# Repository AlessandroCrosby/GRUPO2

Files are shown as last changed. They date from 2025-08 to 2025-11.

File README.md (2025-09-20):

# GRUPO 2
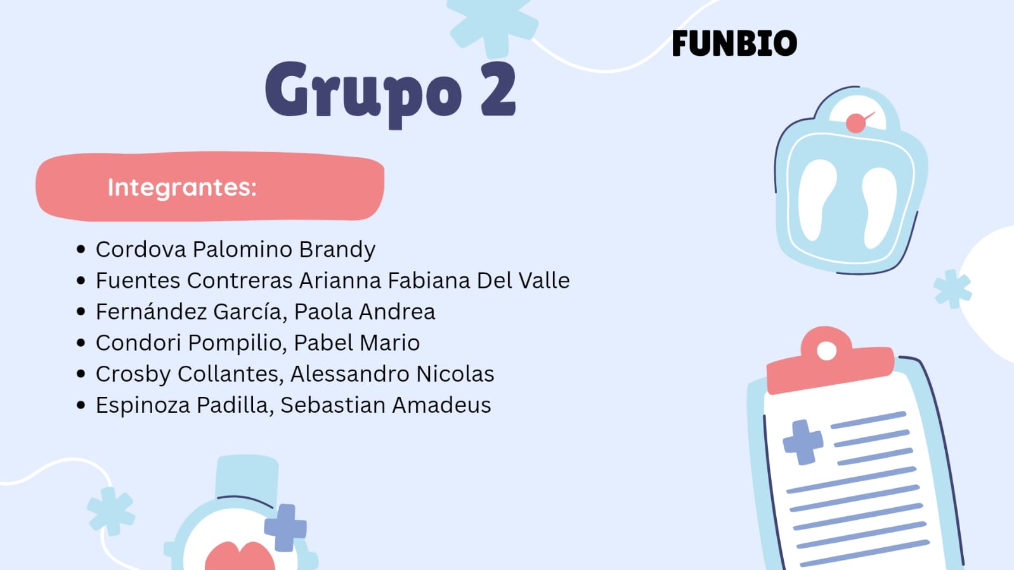
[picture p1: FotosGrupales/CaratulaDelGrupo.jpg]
CaratulaDelGrupo


## Descripción del Equipo - Fundamentos de Biodiseño
Este repositorio contiene el proyecto realizado por el Grupo 2 de estudiantes del 4.° ciclo de Ingeniería Biomédica para el curso de Fundamentos de Biodiseño. Nuestro objetivo fue resolver un desafío real mediante el diseño y desarrollo de un dispositivo biomédico, aplicando conocimiento en electrónica, modelado 3D, investigación y prototipado.

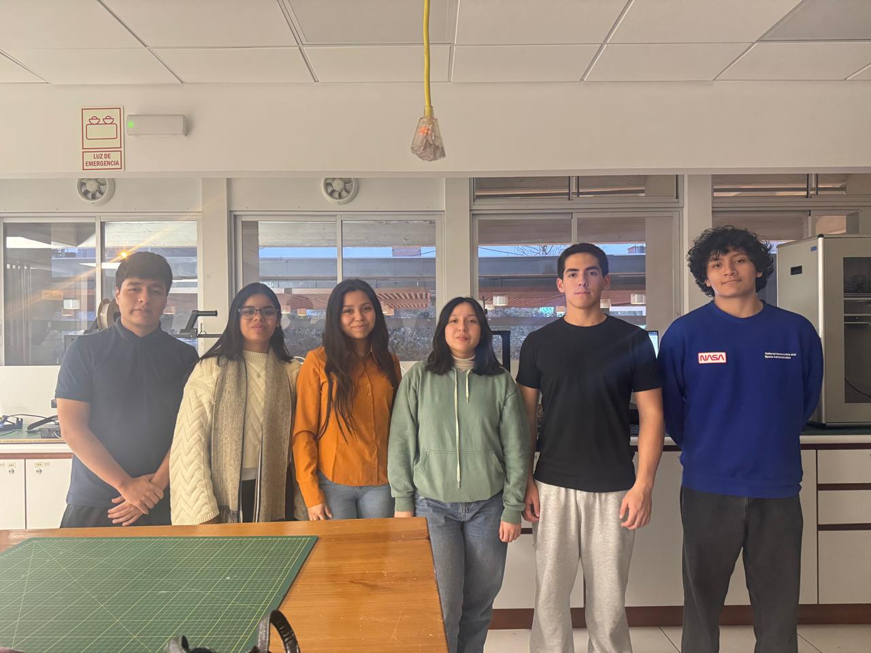
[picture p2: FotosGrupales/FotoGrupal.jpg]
FotoGrupal


## Integrantes del Equipo y Roles

### Condori Pompilio, Pabel Mario
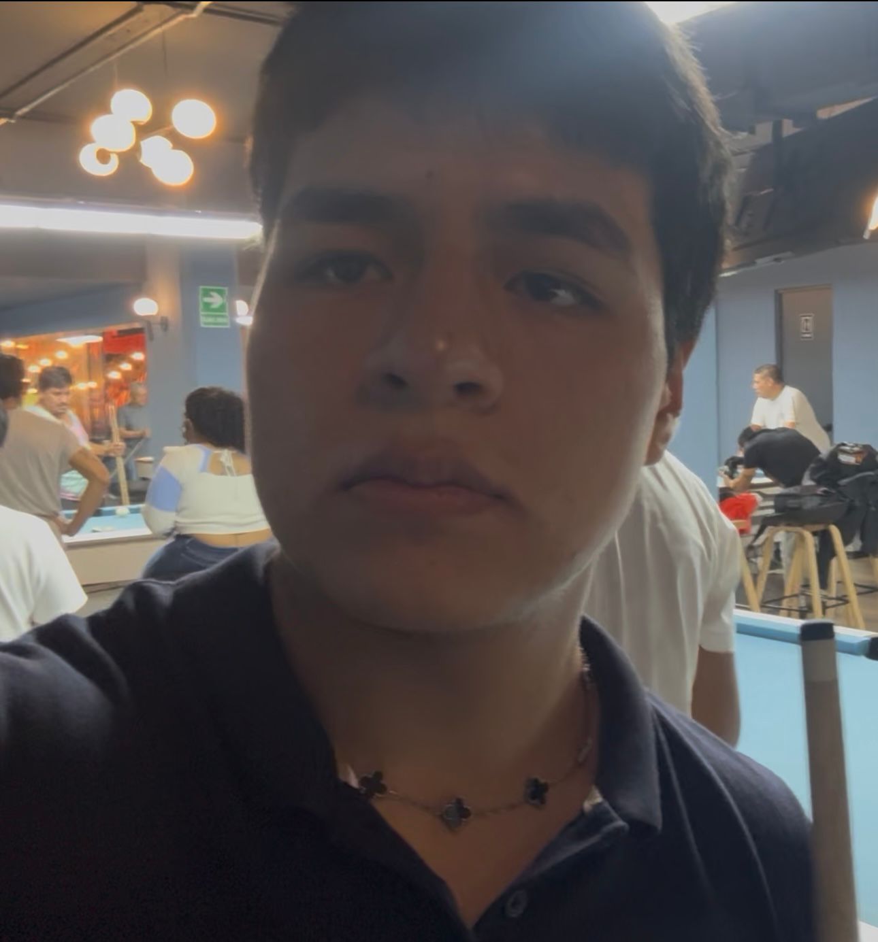
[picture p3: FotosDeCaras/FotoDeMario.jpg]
Mario


- Edad: 19 años
- Sobre mí: Hola soy Mario
- Rol: Modelado 3D
- Responsabilidades:
  - Creación de bocetos y prototipos
  - Selección de materiales

### Cordova Palomino, Brandy Abigail
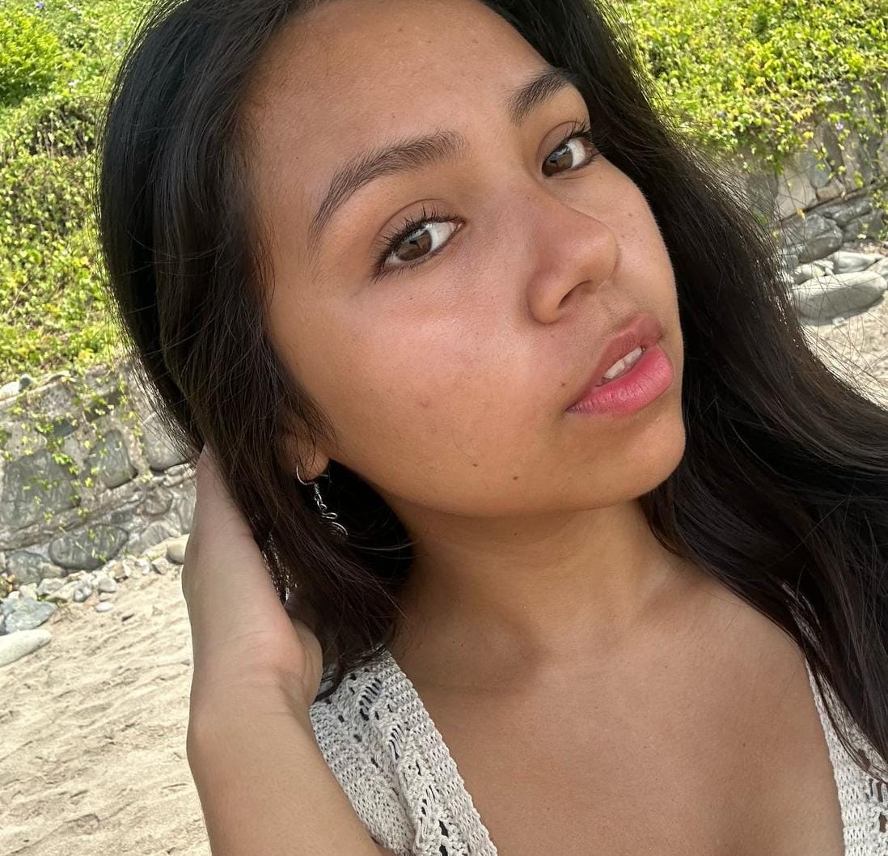
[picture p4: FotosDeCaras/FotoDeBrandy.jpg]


- Edad: 18 años
- Sobre mí: Me gusta cocinar y jugar
- Rol: Modelado 3D y prototipado
- Responsabilidades:
  - Diseño conceptual
  - Creación de bocetos
  - Modelado en 3D
  - Desarrollo en Cura

### Crosby Collantes, Alessandro Nicolas
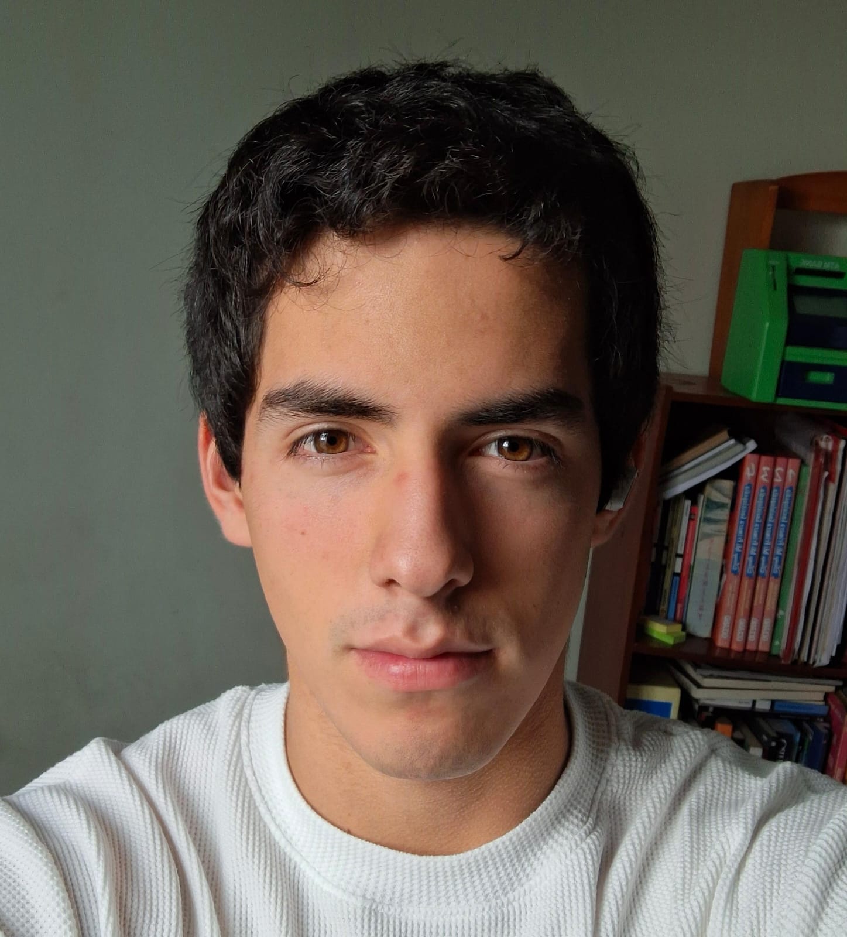
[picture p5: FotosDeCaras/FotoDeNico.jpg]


- Edad: 18 años
- Sobre mí: Me gusta ir al gimnasio y practico powerlifting :3.
- Rol: Gestión del repositorio y quien trae la laptop
- Responsabilidades:
  - Traer la laptop
    
### Espinoza Padilla, Sebastian Amadeus
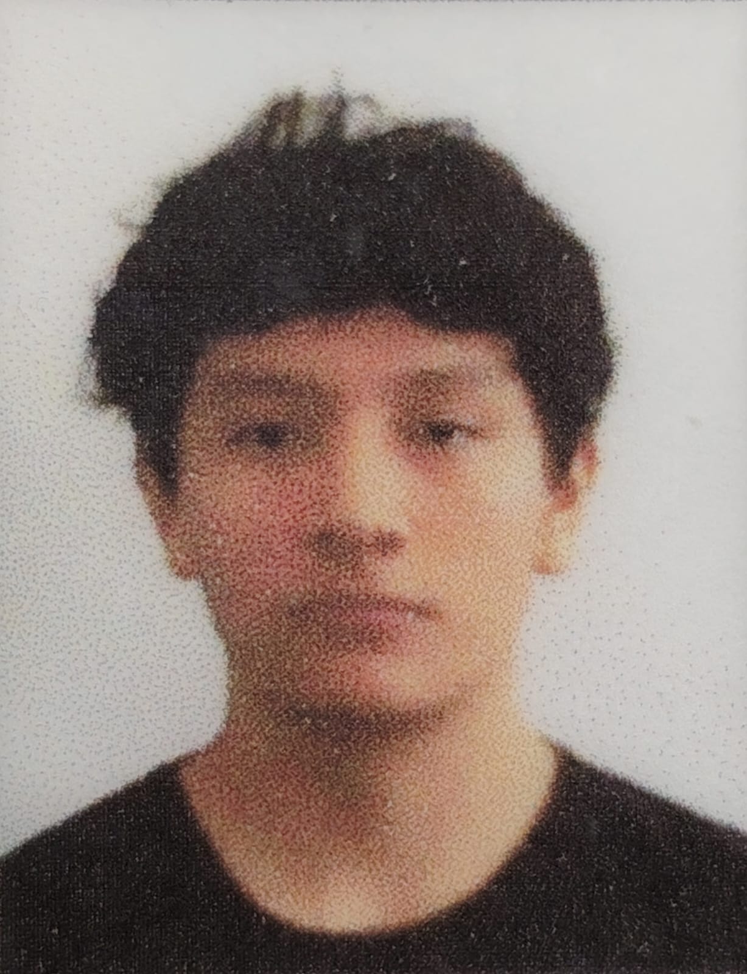
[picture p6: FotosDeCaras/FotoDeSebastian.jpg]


- Edad: 18
- Rol: Electrónica y programación , prototipo, investigador.
- Responsabilidades:
  - Investigación de avances tecnológicos
  - Apoyo en el sistema electrónico y por parte de la programación
  - Apoyo al realizar los bocetos
    
### Fernandez García, Paola Andrea
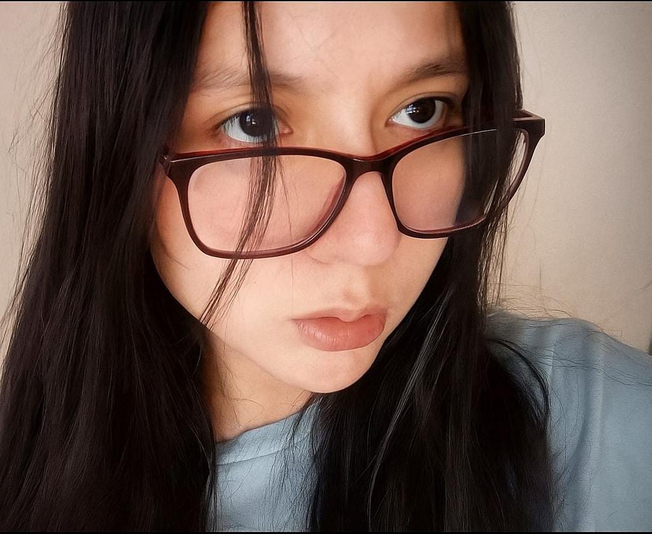
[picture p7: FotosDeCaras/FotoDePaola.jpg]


- Edad: 18
- Sobre mí: Me encanta hacer manualidades y origami. Apasionada por la tecnología.
- Rol: Electrónica
- Responsabilidades:
  - Apoyo en el desarrollo del sistema electrónico
    
### Fuentes Contreras, Arianna Fabiana del Valle
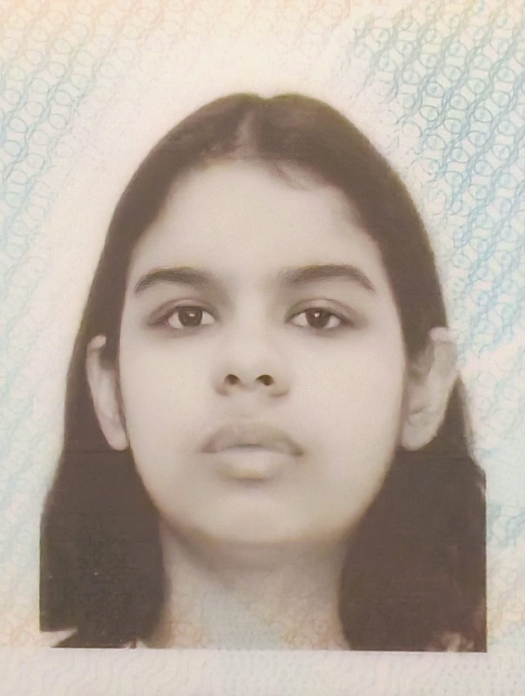
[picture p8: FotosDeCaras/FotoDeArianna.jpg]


- Edad: 18
- Sobre mi: Dibujar, tocar la guitarra, rugby y jugar con mi perro.
- Rol: Diseñadora de prototipo e investigador
- Responsabilidades:
  - Investigacion de tendencias y avances tecnológicos.
  - Realizar bocetos de los prototipos

### Gracias por visitar nuestro repositorio!

### Explora los archivos y conoce más sobre el desarrollo de nuestro dispositivo biomédico

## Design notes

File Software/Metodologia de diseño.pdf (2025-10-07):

# Metodologia de diseño

# CAJA NEGRA (sistema)

## Entradas

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
Captar y procesar
señales oculares | Controlar comandos

Transmitir comando
al controlador

Detectar obstáculos

Retroalimentar al
usuario

Corregir o detener
movimiento

Interpretar y ejecutar
comando

Controlar movimiento
de la silla

# Salidas

# Movimiento controlado de

la silla de ruedas.

## Retroalimentación visual o auditiva sobre el estado del

sistema.

## Mayor autonomía y seguridad

del usuario.

Los servomotores
mueven el brazo
robótico que acciona
el joystick de la silla
de ruedas.

El microcontrolador
convierte los
comandos en
señales para los
servomotores.

El microcontrolador
detiene o ajusta el
movimiento si
detecta peligro.

La app muestra
información sobre el
estado, velocidad,
batería y obstáculos.

Los comandos se
envían al
microcontrolador
(ESP32) mediante
Bluetooth o USB.

Sensores
ultrasónicos miden la
distancia y previenen
colisiones.

La app Eye Tracker
detecta y traduce los
movimientos oculares
en coordenadas para
controlar un cursor.

Los movimientos
oculares generan
comandos de
dirección y velocidad
en la app
“Wheelchair Control”

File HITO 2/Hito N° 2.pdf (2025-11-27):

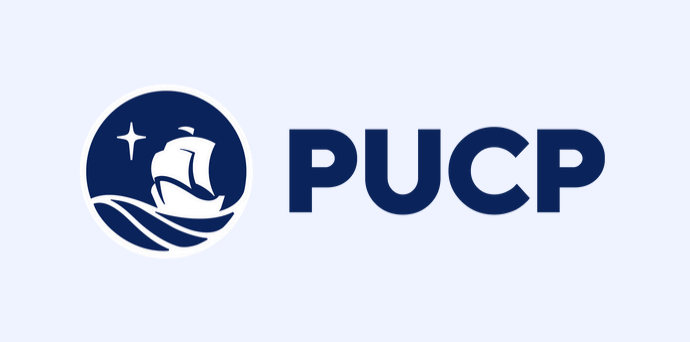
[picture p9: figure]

# EEyyee

# PPii

ll

oott Integrantes: AlessandroNicolasCrosbyCollantes Rol: Líder,creacióndeappmóvil“WheelchairEyeDriving” PabelMarioCondoriPompilio Rol: Hardware Arianna FabianaDelValleFuentesContreras Rol:EncargadadeldesarrollodelaApp PaolaAndrea FernándezGarcía Rol:Ensambladodelprototipo BrandyAbigailCordovaPalomino Rol:EncargadadelModelado3D SebastiánAmadeusEspinozaPadilla Rol: EncargadodelaElectrónica | GGrruuppoo 22

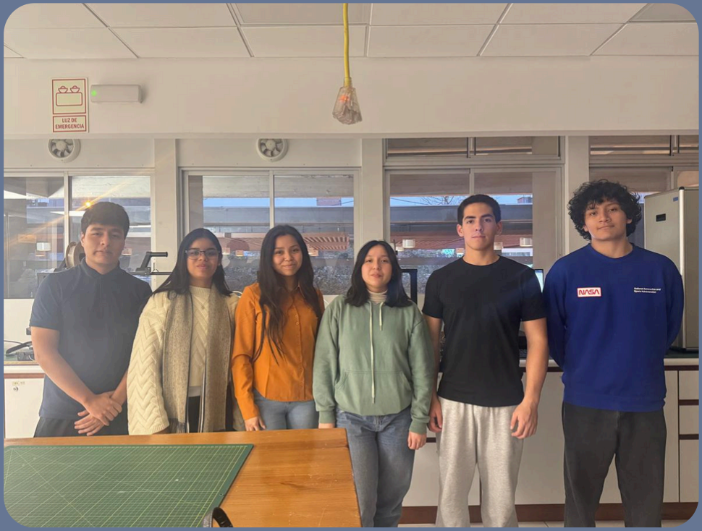
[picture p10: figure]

# PPrroobblleemmááttiiccaa

# Diagnóstico con EM

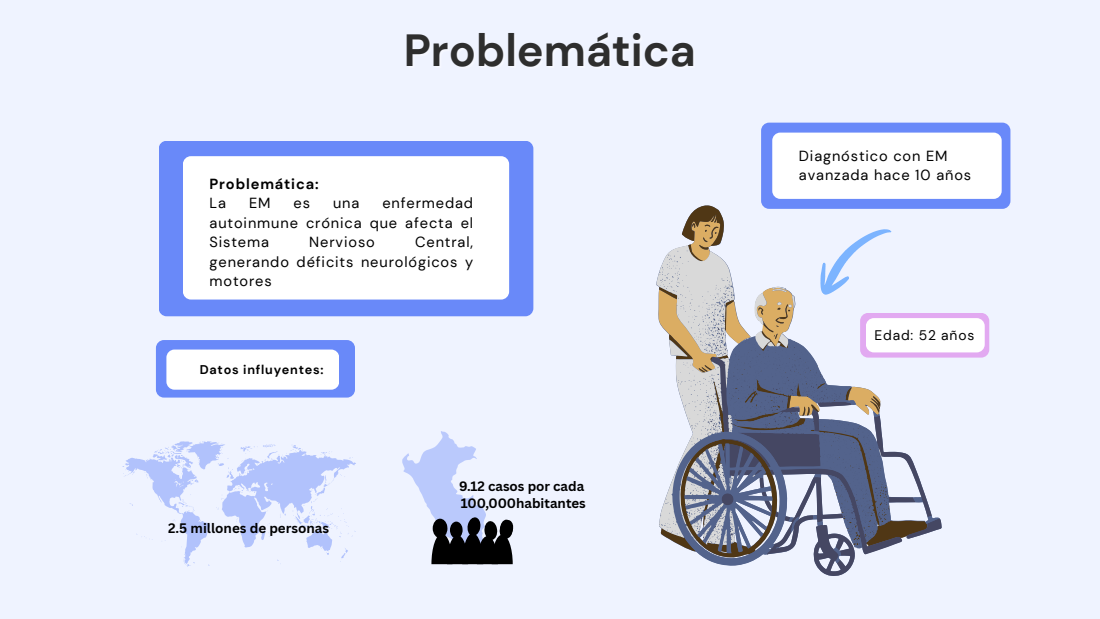
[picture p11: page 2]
Edad: 52; años; una; enfermedad; Sistema; Nervioso; Central,; Datos influyentes:

avanzada hace 10 años

Problemática:
autoinmune crónica que afecta el
generando déficits neurológicos y
motores

9.12 casos por cada
100,000habitantes

2.5 millones de personas

# Referencias Importantes del Estado del Arte

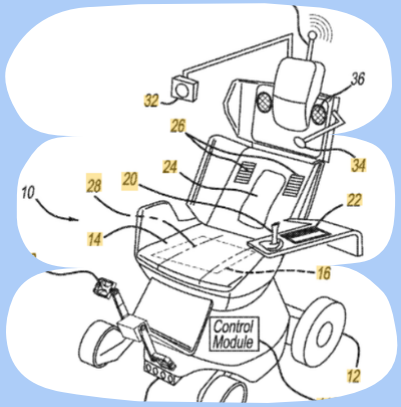
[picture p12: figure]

Sistema | de | control

# electrónico de una silla de ruedas eléctrica con GPS y mando local o remoto

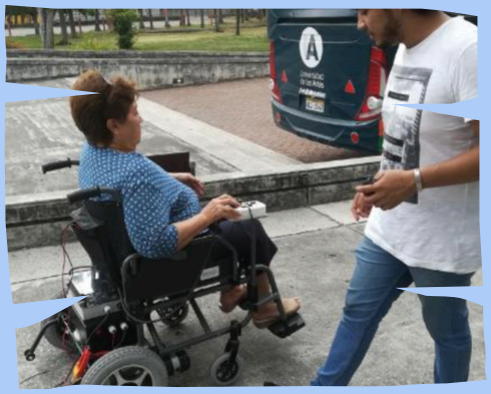
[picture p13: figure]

1 2

# Autonomous Wheelchair (Patente US20170266069A1)

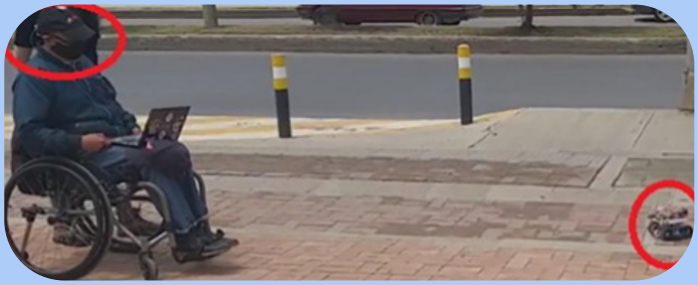
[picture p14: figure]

# 3 Prototipo de silla de ruedas

controlada por posición,
velocidad | y | orientación

# mediante el movimiento de la cabeza

M. M. Olivo Arroyo y E. G. Gallegos Díaz, Diseño e implementación de un sistema de control electrónico de una silla de ruedas eléctrica con ubicación GPS y mando local o remoto a través de una aplicación celular (Android), para personas con discapacidad motriz reducida en miembros inferiores, Universidad Politécnica Salesiana, Guayaquil, Ecuador, 2018. [En línea]. Disponible en: https://dspace.ups.edu.ec/bitstream/123456789/16059/1/UPS-GT002280.pdf
M. Lozano y M. Arceo, «US20170266069A1 - Autonomous wheelchair - Google Patents», 15 de marzo de 2016. Disponible en: https://patents.google.com/patent/US20170266069A1/en
A. X. González-Cely, M. Callejas-Cuervo, y T. Bastos-Filho, «Wheelchair prototype controlled by position, speed and orientation using head movement», HardwareX, vol. 11, p. e00306, abr. 2022, doi: 10.1016/j.ohx.2022.e00306

1 | 2 | TTrraannssmmiissiióónn | 3

# SSoolluucciióónn

# Funcionamiento en tres pasos:

Detección | Acción

# “Control electrónico de silla de ruedas por app con seguimiento facial.”

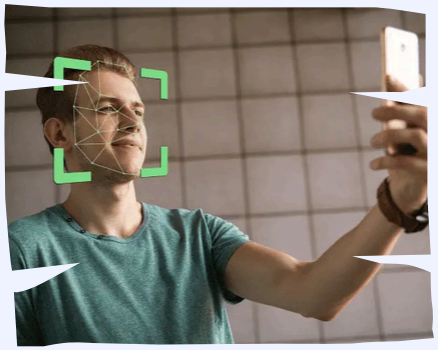
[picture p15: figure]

## La app detecta la cara (face-tracking) y la traduce en coordenadas o comandos

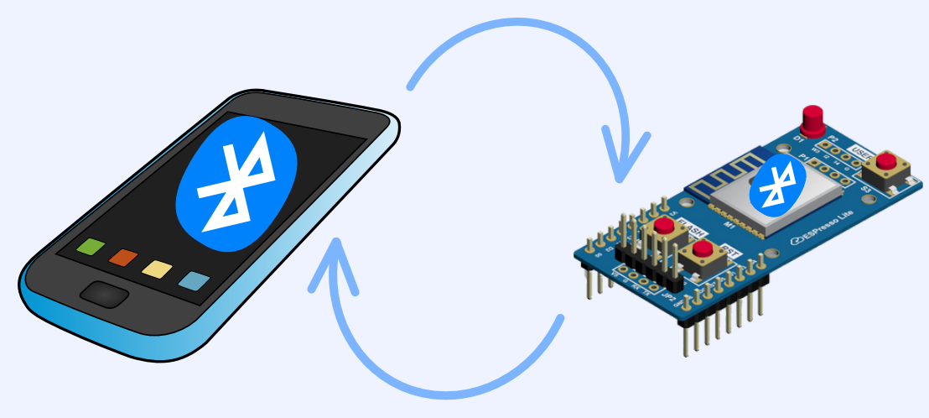
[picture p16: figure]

## El comando se transmite inalambricamente (Bluetooh) al microcontrolador (ESP32) ubicado en la “Brain box”

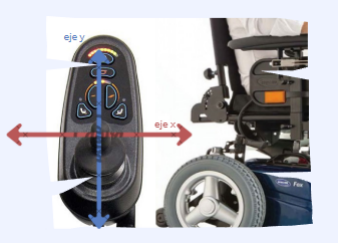
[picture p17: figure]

### El sistema acciona los servomotores de la “Mano Electrónica” que mueven físicamente el joystick de la silla

en el eje x y en el eje y.

Boceto inicial | Modelado 3D

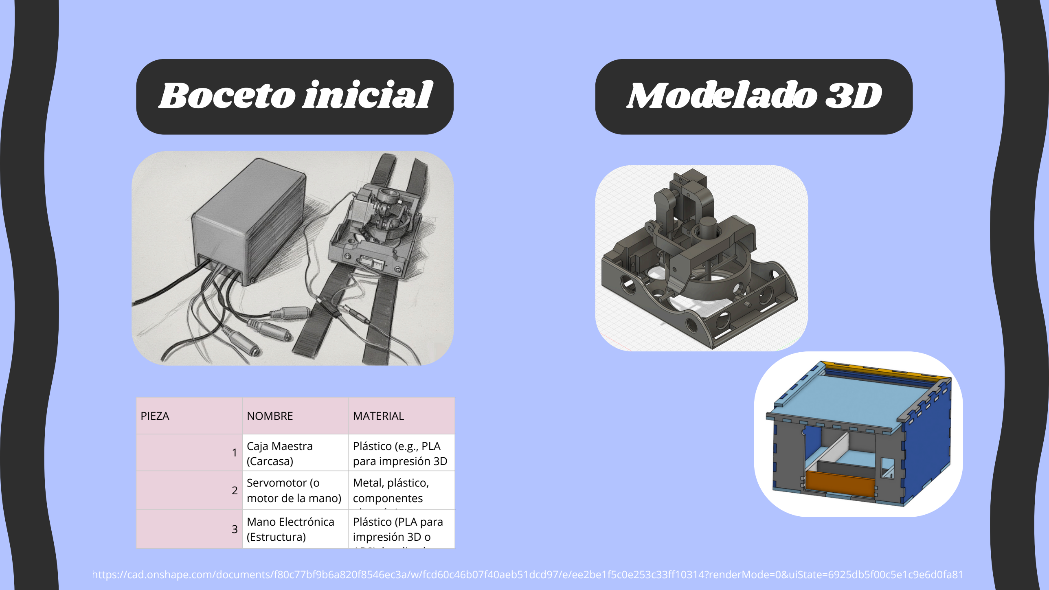
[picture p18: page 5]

PIEZA | NOMBRE | MATERIAL
1 | Caja Maestra (Carcasa) | Plástico (e.g., PLA para impresión 3D
2 | Servomotor (o motor de la mano) | Metal, plástico, componentes
3 | Mano Electrónica (Estructura) | Plástico (PLA para impresión 3D o

https://cad.onshape.com/documents/f80c77bf9b6a820f8546ec3a/w/fcd60c46b07f40aeb51dcd97/e/ee2be1f5c0e253c33ff10314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

# App:EyePilot

Esquema Interno de la App: | Vistas de la App

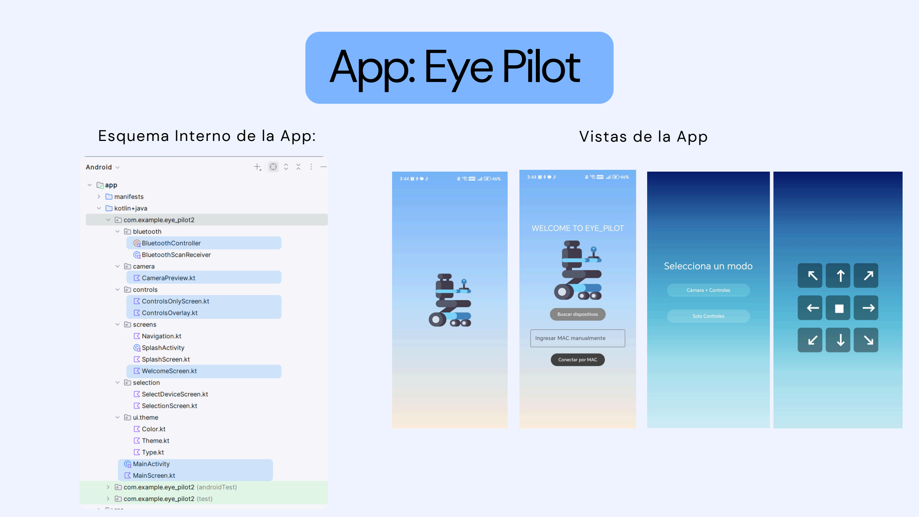
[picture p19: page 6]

# Esquemático del prototipo electrónico

# AAlliimmeennttaacciióónn

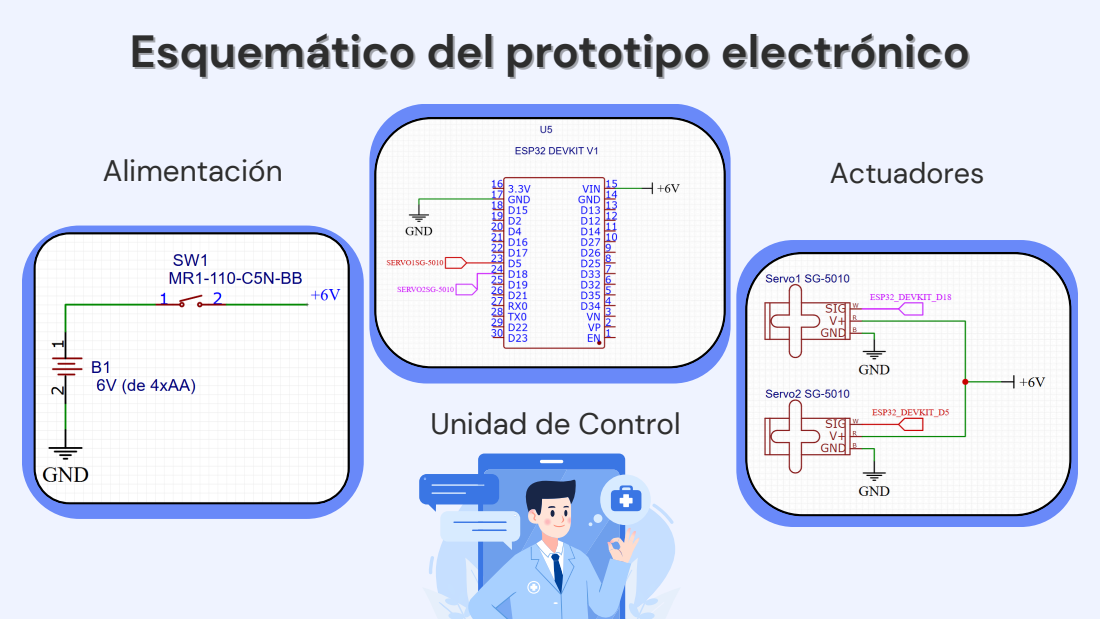
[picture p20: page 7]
AAccttuuaaddoorreess

Unidad de Control

# Componentes electrónicos

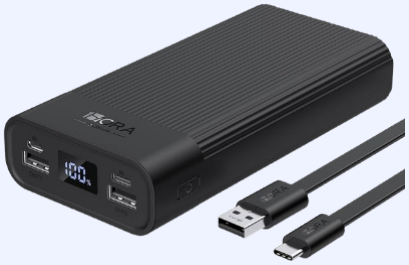
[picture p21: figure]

# Protoboard

# ESP32 DEVKIT V1

# Micro servomotor

# Batería portatil

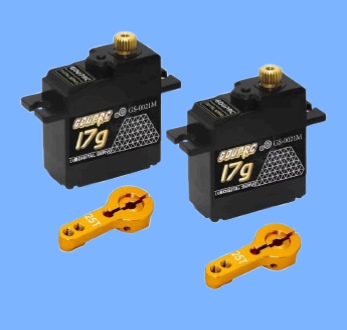
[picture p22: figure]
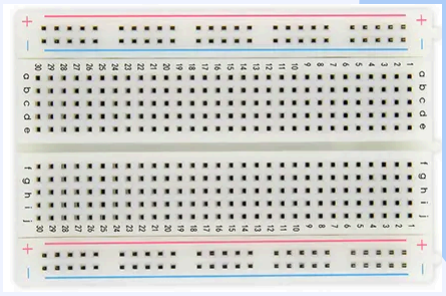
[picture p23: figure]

# Manufactura Digital: Impresión 3D

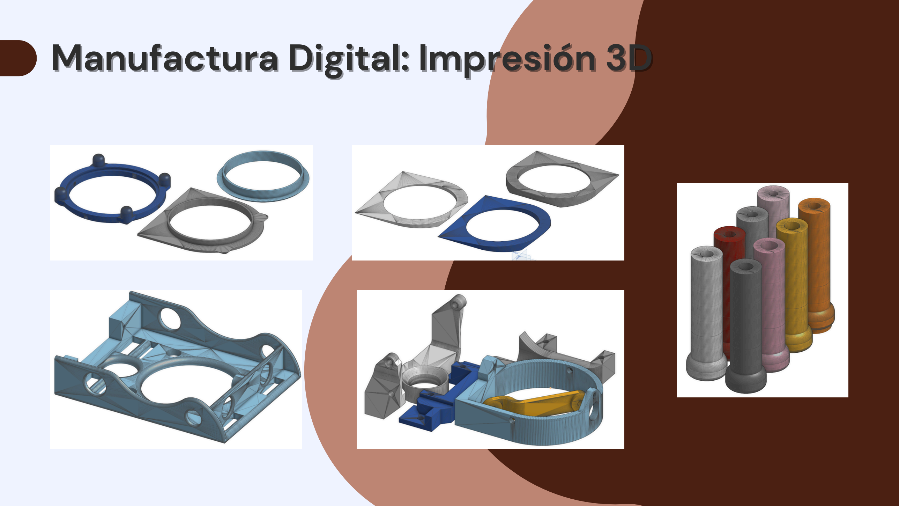
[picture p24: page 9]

# Manufactura Digital: Corte láser

# Switch

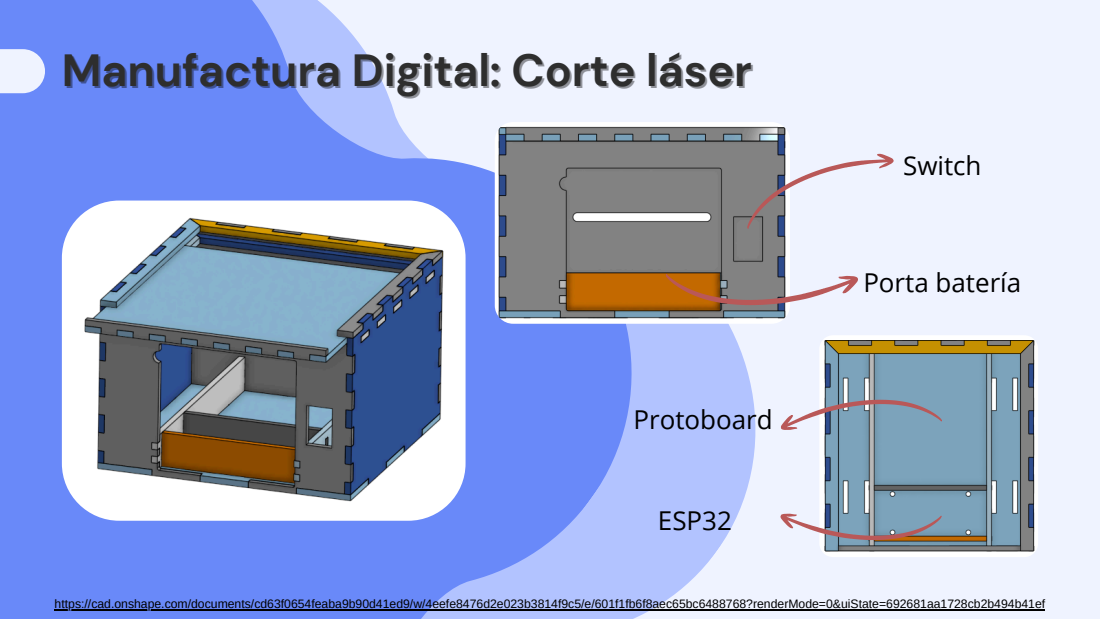
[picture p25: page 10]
Porta batería; Protoboard; ESP32

https://cad.onshape.com/documents/cd63f0654feaba9b90d41ed9/w/4eefe8476d2e023b3814f9c5/e/601f1fb6f8aec65bc6488768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

# Prototipo Integrado

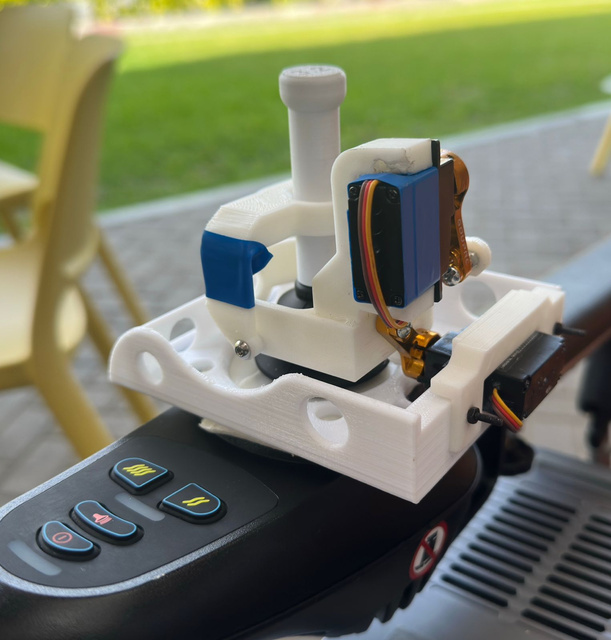
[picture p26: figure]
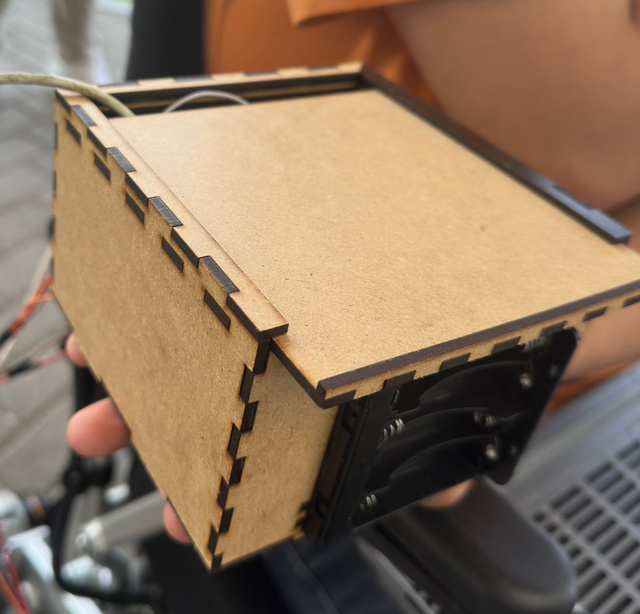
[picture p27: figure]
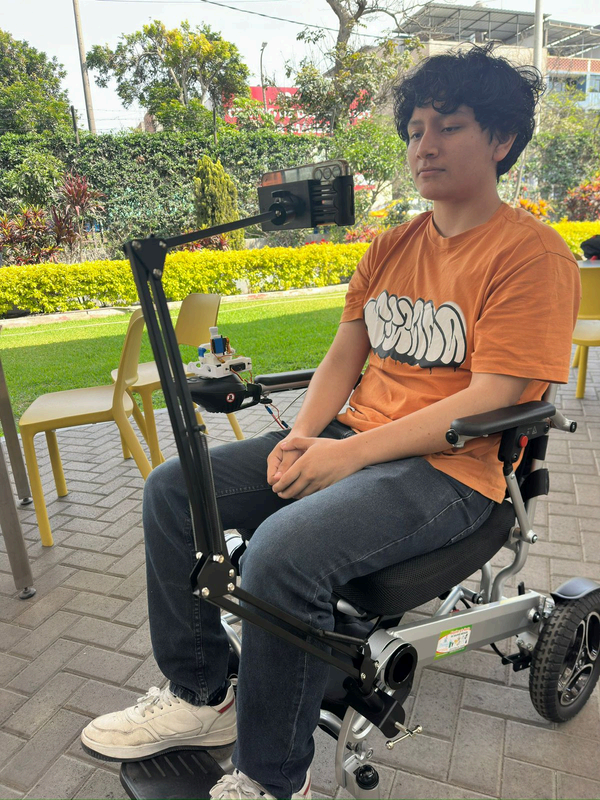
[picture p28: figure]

1 2

# Limitaciones

# Configuración de un Solo Dispositivo para Control y Cámara

# Ausencia de botón de emergencia integrado

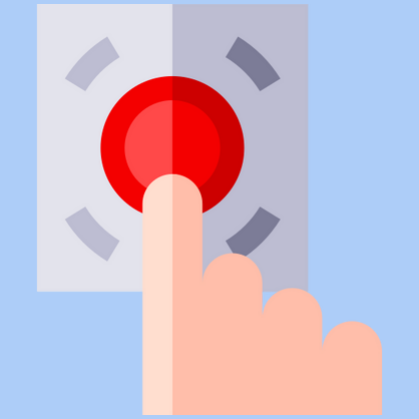
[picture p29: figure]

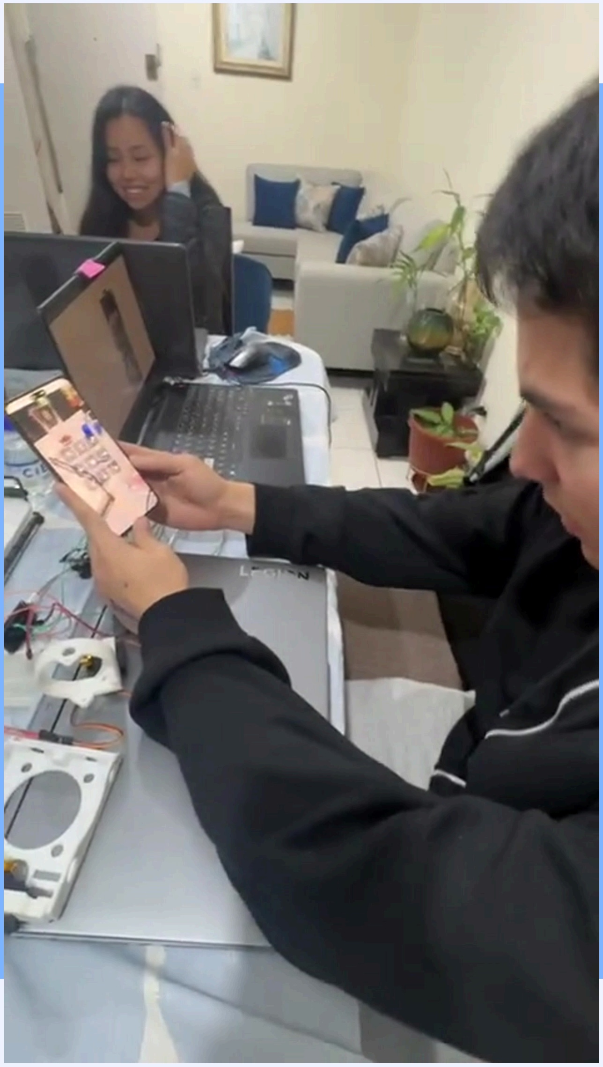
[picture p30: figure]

# Pruebas y Testeos

# Pruebas y Testeos

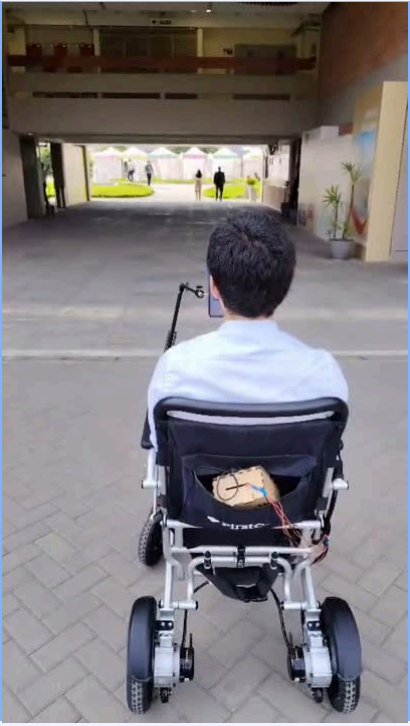
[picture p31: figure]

# Pruebas y Testeos

# Pruebas y Testeos

# MUCHAS

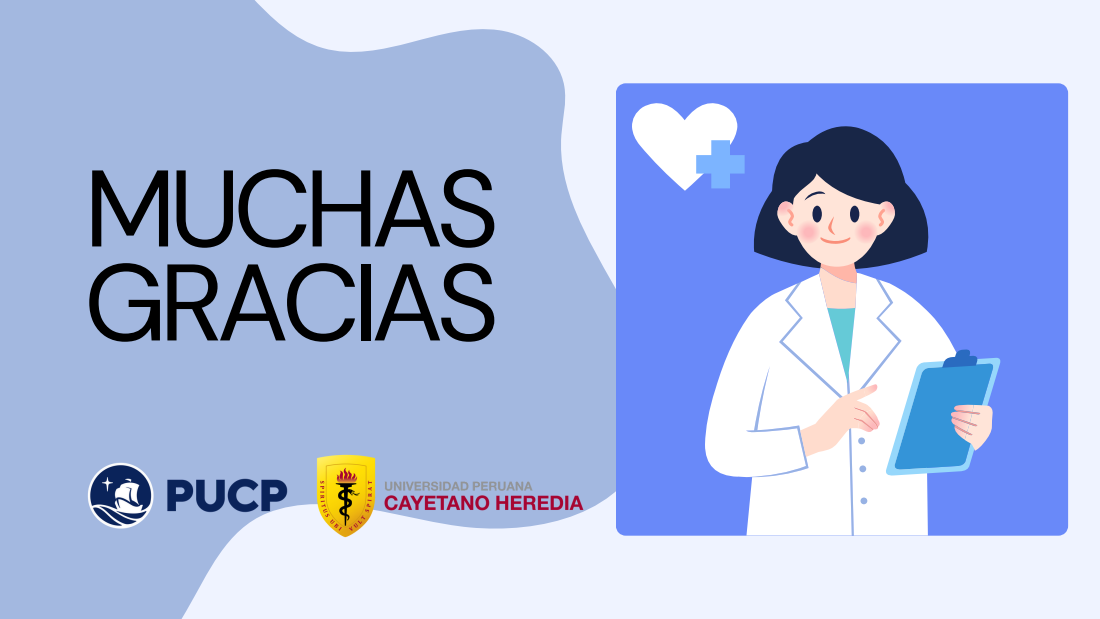
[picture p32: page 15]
GRACIAS

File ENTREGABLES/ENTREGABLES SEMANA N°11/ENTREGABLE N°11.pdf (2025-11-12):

Entregable N°11:

## Integración Hardware - Software - Manufactura digital

Autores:
Alessandro Nicolas Crosby Collantes Pabel Mario Condori Pompilio Arianna Fabiana Del Valle Fuentes Contreras Paola Andrea Fernández García Brandy Abigail Cordova Palomino Sebastián Amadeus Espinoza Padilla

Asesores:
Miguel Rogger Hoyos Alvitez Marco Mugaburu Celi
Shirley Pahuachon Nuñez

Curso:
Fundamentos de Biodiseño – Ciclo IV

Universidad Peruana Cayetano Heredia Facultad de Ciencias e Ingeniería Noviembre 2025

## Verificación de Diseño - SOFTWARE

Tabla de Verificación de Diseño (Software)

Requisito Funcional / No Funcional | Descripción del Componente o Función a Verificar | Método de Verificación (Prueba / Revisión / Simulación) | Criterio de Aceptación | Resultado (Cumple / No cumple) | Observaciones / Recomendacio nes
RF1 – Captar y procesar señales oculares | El sistema debe reconocer la dirección de la mirada y traducirla en comandos. | Prueba funcional en entorno controlado con cámara Android. | Reconocimien to ≥90% en entorno iluminado. | Cumple parcialmente | Precisión baja en baja luz; se recomienda calibración adaptativa.
RF2 – Controlar comandos de movimiento | La app debe interpretar el movimiento ocular para enviar comandos | Simulación con 4 direcciones (arriba, abajo, izq, der) | Tasa de error <10%. | Cumple | Fluidez adecuada, sin retrasos perceptibles.
RF3 – Transmisión Bluetooth | Comunicación entre app Android y módulo ESP32 | Prueba de conexión continua por 60 min. | Pérdida de conexión <1% | Cumple | Comunicación estable durante test prolongado.
RF4 – Interpretación de comandos (ESP32) | Software debe enviar datos correctos a microcontrola dor. | Revisión de código y trazado serial. | Señal reconocida en >95% de casos | Cumple | Comunicación estable, latencia promedio <100 ms.
RF5 – Interfaz de usuario | Interfaz visual clara y accesible | Prueba de usabilidad con usuario simulado | Usuario identifica comandos sin asistencia. | Cumple | Diseño intuitivo, buen contraste visual.
RF6 – Seguridad en fallos | Parada automática en error de conexión. | Simulación de desconexión intencional | Detención inmediata del sistema. | Cumple | Sistema detiene movimiento al perder conexión.

RNF1 – Usabilidad | Curva de aprendizaje ≤15 min. | Evaluación con usuario simulado | 100% comprende funciones básicas en <15 min. | Cumple | Interfaz intuitiva, requiere capacitación mínima.
RNF2 – Rendimiento | Procesamient o fluido sin retrasos notables. | Cronometría de respuesta visual–acción. | Latencia ≤0.2 s. | Cumple | Respuesta inmediata a estímulos visuales.
RNF3 – Fiabilidad | Prueba de operación continua 60 min. | Prueba de estrés. | Sin reinicios ni cuelgues. | Cumple parcialmente | Leve ralentización tras 45 min; optimizar gestión de memoria
RNF4 – Seguridad del sistema | Evita activaciones involuntarias | Pruebas de error ocular y parpadeo. | Activaciones <5%. | Cumple | Confirmación por doble fijación evita falsos positivos.

Tabla de Verificación del Prototipo con Funcionalidades Mixtas (Software / Hardware)

Subsiste ma | Elemento Verificad o | Tipo de Compone nte | Criterio de Verificació n | Resulta do Espera do | Resultad o Obtenido | Cumple / No cumple | Observac iones
Eye-Trac king – App | Procesam iento y transmisi ón de señales | Software + Sensor | Datos reconocidos y enviados correctame nte vía Bluetooth | Señales transmit idas sin pérdida | Transmisi ón estable | Cumple | Comunica ción óptima entre módulos.
App Android – ESP32 | Comunica ción bidireccio nal | Software + Hardware | Sincronizac ión entre interfaz y microcontr olador | Sin retrasos >0.2 s | Latencia 0.1 s | Cumple | Sistema fluido y estable.
ESP32 – Servomot ores | Ejecución de comandos | Software embebido | Comando recibido = movimiento correcto | Movimi ento preciso del joystick | Movimie nto suave y exacto | Cumple | Se mantiene control direccion al correcto.

Botón de emergenci a | Parada inmediata | Hardware + Software | Detención automática ante error | Sistema detiene acción | Cumple | Cumple | Función de seguridad validada.
Sensores ultrasónic os | Detección de obstáculo s | Hardware + Software | Emisión de alerta y corrección de trayectoria | Correcci ón automát ica al detectar objeto | Parcial | No cumple totalment e | Falta respuesta en ángulo ciego lateral.

Evaluación de Requerimientos No Cumplidos o a Replantear

Requisito | Situación Actual | Motivo del Incumplimiento / Riesgo | Acción Correctiva o Replanteamiento
RF1 – Precisión del eye-tracking | Cumple parcialmente | Variabilidad por condiciones de iluminación | Implementar calibración dinámica o sensor infrarrojo.
RNF3 – Fiabilidad (uso prolongado) | Cumple parcialmente | Gestión ineficiente de memoria en app | Optimizar código y liberar buffers tras cada sesión.
Sensor ultrasónico lateral | No cumple completamente | Ángulo muerto no cubierto por el sensor | Añadir sensor adicional o algoritmo de fusión de datos.

## Verificación de Diseño - Hardware

Tabla de Verificación de Diseño (Hardware)

Componente / Subsistema | Método de verificación | Criterio de aceptación | Resultado | Observaciones / Recomendaciones
Carcasa + ESP32 + batería + drivers + cableado | Medición con balanza | ≤ 0.80 kg | Cumple | Aunque con las bases que se tenía cumple, se realizarán pruebas con todo completo
Batería + consumo total | Prueba en uso continuo (movimientos/ BT) | ≥ 4 h | No cumple totalmente | Realizar unas pruebas más para tener bien en claro

E-STOP + lógica de corte | Prueba física: pulsación durante movimiento | Detención inmediata | Cumple | Se detiene si la persona no esta mirando ademas de desactivar el mecanismo en cualquier momento con el switch
Power / Reset accesibles | Inspección + prueba | Accesibles sin herramientas | Cumple | Reubicar si hay interferencias con el apoyabrazos, aun se realizara prueba.
Carcasa y anclajes | Inspección + plantilla | No invade ruedas/apoyab razos; no juego >2 mm | Cumple | En teoría cumple pero se realizará prueba.
Carcasa + soportes | Prueba de vibración/golp e leve | Sin fisuras; tornillos sin aflojar | Cumple | En teoría cumple pero se realizará prueba.
Servomotores + acople a joystick | Prueba funcional con cargas | Par ≥ requerido; seguimiento suave | Cumple | En teoría cumple pero se realizará prueba.
LEDs/buzzer | Prueba de patrones | Estados distinguibles (conectado, error, stop) | Cumple | En la aplicación podrá observarse el estado
Drivers/servos /carcasa | Medición con termómetro IR | Carcasa <45 °C; driver <70 °C | Cumple | No se usará ventilación pero las siguiente pruebas de uso lo determinaran mejor

Vídeo del funcionamiento piloto de EyePilot: https://youtube.com/shorts/qDQIfGdBrkY?feature=share


Foto del prototipo:

Código del Arduino IDE:



Códigos del Android App Studio:

- Código 1:


- Código 2:

package com.example.eyepilot_app

import android.Manifest

import android.bluetooth.BluetoothAdapter

import android.bluetooth.BluetoothDevice

import android.bluetooth.BluetoothManager

import android.content.pm.PackageManager

import android.os.Build

import android.os.Bundle

import android.util.Log

import androidx.activity.ComponentActivity

import androidx.activity.compose.setContent

import androidx.activity.compose.rememberLauncherForActivityResult

import androidx.activity.result.contract.ActivityResultContracts

import androidx.camera.core.CameraSelector

import androidx.camera.core.Preview

import androidx.camera.lifecycle.ProcessCameraProvider

import androidx.camera.view.PreviewView

import androidx.compose.foundation.layout.*

import androidx.compose.material3.Scaffold

import androidx.compose.runtime.*

import androidx.compose.ui.Alignment

import androidx.compose.ui.Modifier

import androidx.compose.ui.viewinterop.AndroidView import androidx.core.content.ContextCompat

import androidx.lifecycle.compose.LocalLifecycleOwner

class MainActivity : ComponentActivity() {

private var bluetoothAdapter: BluetoothAdapter? = null

private val espMac = "00:22:04:AB:CD:EF"

override fun onCreate(savedInstanceState: Bundle?) {

super.onCreate(savedInstanceState)

setContent {

CameraPreview(modifier = Modifier.fillMaxSize())

}

val bluetoothManager = getSystemService(BLUETOOTH_SERVICE) as BluetoothManager

bluetoothAdapter = bluetoothManager.adapter

requestBluetoothPermissions()

connectToESP()

setContent {

Scaffold(modifier = Modifier.fillMaxSize()) { padding ->

val lifecycleOwner = LocalLifecycleOwner.current

var hasCameraPermission by remember { mutableStateOf(false) }

val cameraPermissionLauncher = rememberLauncherForActivityResult(

contract = ActivityResultContracts.RequestPermission(),

onResult = { granted: Boolean -> hasCameraPermission = granted }

)

LaunchedEffect(Unit) {

cameraPermissionLauncher.launch(Manifest.permission.CAMERA)

}

Box(

modifier = Modifier

.fillMaxSize()

.padding(padding)

) {

if (hasCameraPermission) {

CameraPreview(

modifier = Modifier.fillMaxSize(),

lifecycleOwner = lifecycleOwner

)

}

ControlsOverlay(

modifier = Modifier.align(Alignment.Center),

sendCommand = { cmd -> BluetoothController.sendCommand(cmd) }

)

}

}

}

}

private fun requestBluetoothPermissions() {

if (Build.VERSION.SDK_INT >= Build.VERSION_CODES.S) {

val permissions = arrayOf(

Manifest.permission.BLUETOOTH_CONNECT,

Manifest.permission.BLUETOOTH_SCAN

)

val missing = permissions.any {

checkSelfPermission(it) != PackageManager.PERMISSION_GRANTED

}

if (missing) {

requestPermissions(permissions, 1001)

}

}

}

private fun connectToESP() {

try {

val device: BluetoothDevice? = bluetoothAdapter?.getRemoteDevice(espMac)

if (device != null) {

BluetoothController.connect(device)

} else {

Log.e("BT", "Device not found")

}

} catch (e: SecurityException) {

Log.e("BT", "Permission denied", e)

}

}

}

@Composable

fun CameraPreview(

modifier: Modifier,

lifecycleOwner: androidx.lifecycle.LifecycleOwner

) {

AndroidView(

modifier = modifier,

factory = { ctx ->

val previewView = PreviewView(ctx)

val cameraProviderFuture = ProcessCameraProvider.getInstance(ctx)

cameraProviderFuture.addListener({

val cameraProvider = cameraProviderFuture.get()

val preview = Preview.Builder().build().also {

it.setSurfaceProvider(previewView.surfaceProvider)

}

try {

cameraProvider.unbindAll()

cameraProvider.bindToLifecycle(

lifecycleOwner,

CameraSelector.DEFAULT_BACK_CAMERA,

preview

)

} catch (e: Exception) {

e.printStackTrace()

}

}, ContextCompat.getMainExecutor(ctx))

previewView

}

)

}

- Código 3:

package com.example.eyepilot_app

import androidx.compose.foundation.layout.*

import androidx.compose.foundation.shape.RoundedCornerShape

import androidx.compose.material3.Button

import androidx.compose.material3.ButtonDefaults

import androidx.compose.material3.Text

import androidx.compose.runtime.Composable

import androidx.compose.ui.Alignment

import androidx.compose.ui.Modifier

import androidx.compose.ui.graphics.Color

import androidx.compose.ui.unit.dp

import androidx.compose.ui.unit.sp

import androidx.compose.ui.text.font.FontWeight

import androidx.compose.ui.res.painterResource

import androidx.compose.foundation.Image

@Composable

fun ControlsOverlay(modifier: Modifier = Modifier, sendCommand: (String) -> Unit) {

val buttonModifier = Modifier.size(80.dp).padding(5.dp)

val color = ButtonDefaults.buttonColors(containerColor = Color.Black.copy(alpha = 0.4f))

Column(

modifier = modifier,

horizontalAlignment = Alignment.CenterHorizontally,

verticalArrangement = Arrangement.Center

) {

Row {

Button(onClick = { sendCommand("UP_LEFT") },

modifier = buttonModifier, colors = color, shape = RoundedCornerShape(9.dp)) { Text("↖", fontSize = 38.sp, fontWeight = FontWeight.Bold) }

Button(onClick = { sendCommand("UP") },

modifier = buttonModifier, colors = color, shape = RoundedCornerShape(9.dp)) { Text("↑", fontSize = 38.sp, fontWeight = FontWeight.Bold) }

Button(onClick = { sendCommand("UP_RIGHT") },

modifier = buttonModifier, colors = color, shape = RoundedCornerShape(9.dp)) { Text("↗", fontSize = 38.sp, fontWeight = FontWeight.Bold) }

}

Spacer(Modifier.height(12.dp))

Row {

Button(onClick = { sendCommand("LEFT") }, modifier = buttonModifier, colors = color, shape = RoundedCornerShape(9.dp)) { Text("←", fontSize = 38.sp, fontWeight = FontWeight.Bold) }

Button(onClick = { sendCommand("STOP") },

modifier = buttonModifier, colors = color, shape = RoundedCornerShape(9.dp)) { Text("■", fontSize = 38.sp, fontWeight = FontWeight.Bold) }

Button(onClick = { sendCommand("RIGHT") },

modifier = buttonModifier, colors = color, shape = RoundedCornerShape(9.dp)) { Text("→", fontSize = 38.sp, fontWeight = FontWeight.Bold) }

}

Spacer(Modifier.height(12.dp))

Row {

Button(onClick = { sendCommand("DOWN_LEFT") },

modifier = buttonModifier, colors = color, shape = RoundedCornerShape(9.dp)) { Text("↙", fontSize = 38.sp, fontWeight = FontWeight.Bold) }

Button(onClick = { sendCommand("DOWN") },

modifier = buttonModifier, colors = color, shape = RoundedCornerShape(9.dp)) { Text("↓", fontSize = 38.sp, fontWeight = FontWeight.Bold) }

Button(onClick = { sendCommand("DOWN_RIGHT") },

modifier = buttonModifier, colors = color, shape = RoundedCornerShape(9.dp)) { Text("↘", fontSize = 38.sp, fontWeight = FontWeight.Bold) }

}

}

}

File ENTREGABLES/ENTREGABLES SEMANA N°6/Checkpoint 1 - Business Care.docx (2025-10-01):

Checkpoint 1 – Business Case

1. Situación inicial
El paciente con esclerosis múltiple avanzada presenta disartria severa y habla ininteligible, lo que limita su autonomía comunicativa, participación social y calidad de vida. Los sistemas de comunicación actuales que ha probado son lentos, poco accesibles y requieren esfuerzos físicos/cognitivos que aumentan su fatiga.

2. Objetivos estratégicos

- Técnicos: Desarrollar un sistema aumentativo y alternativo de comunicación (SAAC) multimodal (control ocular, gestual o BCI) que sea accesible, personalizable y de bajo esfuerzo.
- Económicos: Prototipo de bajo costo en comparación con soluciones comerciales (>10,000 USD).
- Organizativos: Integrar al equipo interdisciplinario (ingenieros biomédicos, terapeutas de lenguaje, médicos rehabilitadores) en un proceso de co-diseño con la familia del paciente.

3. Valor añadido

- Usuario: Autonomía comunicativa y emocional, reducción del aislamiento social.
- Empresa/Universidad: Desarrollo de prototipo biomédico con potencial de escalamiento y aplicación en otros pacientes con disartria severa.
- Sociedad: Mejora de inclusión y accesibilidad tecnológica para personas con discapacidades motoras y del habla.

4. Stakeholders

- Usuario final: Paciente con EM avanzada y disartria severa.
- Cuidadores primarios: Esposa e hijo adolescente.
- Equipo clínico: Neurólogo, fisiatra, terapeuta de lenguaje, fisioterapeuta, psicólogo.
- Otros: Institución académica, posibles fabricantes de dispositivos médicos, aseguradoras de salud.

5. Competencias y equipo

- Conocimiento de bioinstrumentación, electrónica, interfaces HMI, software accesible y procesamiento de señales biomédicas.
- Apoyo clínico en logopedia y rehabilitación para validar el sistema.
- Recursos disponibles: laboratorio universitario, open-hardware (OpenBCI), licencias de software de desarrollo.

6. Planificación inicial

- Cronograma preliminar:
  - Semana 1–2-3-4: investigación de usuario y benchmarking de tecnologías.
  - Semana 5-6-7-8: diseño conceptual, selección de sensores y hardware.
  - Semana 9-10-11-12: prototipado inicial y pruebas en laboratorio.
  - Semana 13-14-15-16: pruebas piloto con paciente, iteración de mejoras.
- Presupuesto inicial: S/.200–300 (hardware, sensores, software, manufactura).
- Riesgos:
  - Fatiga ocular o deterioro visual limita el uso de eye-tracking.
  - Problemas de usabilidad (interfaz demasiado compleja).
  - Falta de financiamiento sostenido.
  - Aceptación del usuario/familia si el sistema no se adapta a sus rutinas.

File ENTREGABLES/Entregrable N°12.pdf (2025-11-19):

### Entregable N°12:

### Pruebas de uso del prototipo de baja fidelidad según plan de usabilidad

### Autores:

### Alessandro Nicolas Crosby Collantes Pabel Mario Condori Pompilio Arianna Fabiana Del Valle Fuentes Contreras Paola Andrea Fernández García Brandy Abigail Cordova Palomino Sebastián Amadeus Espinoza Padilla

### Asesores:

### Miguel Rogger Hoyos Alvitez Marco Mugaburu Celi Shirley Pahuachon Nuñez

### Curso:

### Fundamentos de Biodiseño – Ciclo IV

### Universidad Peruana Cayetano Heredia Facultad de Ciencias e Ingeniería

### Noviembre 2025

Pruebas de uso del prototipo de baja fidelidad según plan de usabilidad

Sección del plan | ¿Qué es? | ¿Qué hacer? | Evidencia
1. Contexto
de uso

El dispositivo será utilizado por personas con esclerosis múltiple
avanzada, | una | enfermedad
neurodegenerativa | que | reduce
progresivamente la motricidad fina y gruesa, volviendo cada vez más difícil manipular un joystick convencional para controlar una silla de ruedas. No obstante, estas
personas | conservan | suficiente
control de cabeza y mirada para interactuar con la aplicación móvil que forma parte del prototipo.


El prototipo consiste en un sistema de control alternativo donde una app Android detecta movimientos simples de cabeza o de la mirada y envía comandos vía Bluetooth a un
ESP32. | Este | microcontrolador
acciona dos servomotores que mueven físicamente el joystick de la silla, los cuales están integrados en un soporte que va alrededor del
joystick. | Los | servos | poseen
diferentes grados de movimiento de forma que logren mover el joystick en distintas direcciones de

El usuario principal del proyecto es una persona adulta con esclerosis múltiple avanzada, una enfermedad neurodegenerativa que ocasiona una discapacidad motriz severa, limitando de forma considerable los movimientos voluntarios de los brazos y manos. Debido a estas restricciones, el usuario no puede operar un joystick convencional de silla de ruedas, lo que reduce su autonomía y dificulta su desplazamiento cotidiano, lo cual como consecuencia le produce un notable deterioro en su vida social y personal. Sin embargo, debido a que conserva un adecuado control ocular, cervical y cognitivo, lo que le permite realizar movimientos de cabeza o dirigir la mirada para activar comandos simples sin generar esfuerzo adicional.

El usuario secundario corresponde al terapeuta o cuidador encargado de asistir durante las primeras sesiones. Su intervención es necesaria para calibrar el sistema, supervisar la interacción del paciente con el prototipo y garantizar un funcionamiento seguro, especialmente porque el usuario principal no puede manipular la app ni realizar ajustes mecánicos debido a sus limitaciones motoras.

El prototipo está diseñado para utilizarse en entornos controlados, como clínicas de rehabilitación, hospitales y zonas exteriores seguras preparadas exclusivamente para prácticas guiadas. En esta etapa del desarrollo, el



manera precisa para simular los movimientos que normalmente haría la mano del usuario. Asimismo, el prototipo también
tendrá | una | caja | en | forma
rectangular que permita ordenar y resguardar los componentes usados
para | el | funcionamiento | del
prototipo, | dicha | caja deberá
adherirse a la silla eléctrica y tendrá un sets de fundas de diferentes tamaños que se acoplen a los joysticks.


El uso del prototipo se realizará
principalmente | en | entornos
controlados, como clínicas de rehabilitación, hospitales o áreas exteriores seguras, garantizando condiciones estables y supervisadas durante las pruebas.

sistema incorpora únicamente un botón de parada de emergencia, que permite detener inmediatamente el movimiento de la silla ante cualquier situación de riesgo. Además, el prototipo cuenta con un mecanismo de seguridad mediante el cual, si la conexión Bluetooth se interrumpe, los servomotores dejan de moverse y el joystick retorna automáticamente a su posición neutral, evitando desplazamientos imprevistos.

Los sensores ultrasónicos no forman parte del prototipo actual, pero están proyectados para implementarse en una versión futura destinada a espacios exteriores reales, donde la presencia de obstáculos, vehículos o personas exige sistemas adicionales de prevención de colisiones.

La frecuencia y duración de uso dependerá del estado físico del paciente, considerando que la esclerosis múltiple avanzada se caracteriza por fatiga y debilidad muscular fluctuante. Por ello, se plantea un plan progresivo con sesiones, lo cual permite que el usuario se familiarice gradualmente con el sistema y practique sus movimientos sin comprometer su seguridad. Sin embargo, debido a la simplicidad de ejecución del prototipo no será necesario un lapso muy extenso de asimilación.

2. Perfil del
usuario El perfil del usuario corresponde a la descripción detallada de sus características físicas, cognitivas y emocionales, con el fin de

Para adaptar el dispositivo a las necesidades reales del usuario, se debe realizar un análisis detallado de posibles limitaciones visuales, motoras, cognitivas o de comprensión. Este proceso permite determinar las

La evidencia utilizada para este análisis proviene de registros clínicos, de la funcionalidad inicial documentada y de las evaluaciones correspondientes al caso. En comprender sus necesidades reales frente al uso del dispositivo. En este caso, el usuario es un hombre de 52 años con diagnóstico de Esclerosis Múltiple avanzada y disartria severa, condiciones que determinan de manera significativa
su | capacidad | motora, | su
comunicación y su interacción con el entorno.

Desde el punto de vista físico, los registros clínicos indican que el
usuario | presenta | debilidad
muscular generalizada con una fuerza de 3 sobre 5 en la escala muscular. Según el examen clínico, también manifiesta fatiga fácil ante esfuerzos moderados, lo cual limita
la | posibilidad | de | sostener
movimientos prolongados o de precisión. Se documenta además un control parcial de la micción y del intestino, un apetito conservado y una emisión verbal ininteligible,
evidenciando | una | alteración
comunicativa severa asociada a la disartria.

En relación con sus características cognitivas, la evaluación clínica reporta que el usuario mantiene un capacidades funcionales actuales y anticipar ajustes necesarios en la interfaz o en el modo de interacción.

En la evaluación de las limitaciones motoras, los datos clínicos muestran que la debilidad generalizada y la fatiga fácil dificultan movimientos finos y sostenidos, por lo que se requieren mecanismos de control con mínimo esfuerzo físico. En cuanto a las limitaciones visuales, aunque no se han registrado alteraciones visuales específicas, la Esclerosis Múltiple puede asociarse con visión borrosa o nistagmo; por ello, se recomienda el uso de alto contraste y elementos visuales amplios como medida preventiva. Respecto a las limitaciones cognitivas, la documentación clínica señala que el usuario conserva la comprensión y la lucidez, aunque la fatiga podría disminuir su capacidad de concentración con el tiempo. Finalmente, en la revisión de las limitaciones de comprensión, se confirma que entiende adecuadamente el lenguaje oral, escrito y simbólico, pero su emisión verbal es ininteligible, lo que exige implementar sistemas de comunicación aumentativa con retroalimentación visual clara.

cuanto a las limitaciones motoras, el examen clínico señala textualmente: “Motricidad: debilidad generalizada (3/5), fatiga fácil”, lo que confirma la necesidad de interfaces de bajo esfuerzo. Con respecto a las capacidades cognitivas y de comprensión, la evaluación indica que el usuario se encuentra lúcido y es capaz de comprender órdenes simples y complejas, y los registros de lenguaje describen
“emisión | verbal | ininteligible,
comunicación limitada”, lo cual coincide con la observación funcional de que “puede comprender y responder con gestos”. En relación con el estado emocional, las funciones biológicas reportan “ánimo bajo”, evidenciando un impacto en su bienestar emocional. Finalmente, los documentos diagnósticos confirman la presencia de “disartria severa y pérdida parcial del habla en paciente con EM avanzada”, lo que justifica la clasificación de la comunicación oral como una necesidad crítica y altamente limitada.

estado de conciencia lúcido y conserva la comprensión tanto de órdenes simples como complejas. De acuerdo con la funcionalidad inicial, es capaz de responder mediante gestos u otras formas no verbales, lo que evidencia que su
capacidad | de | comprensión
permanece intacta, a pesar de la limitación para emitir lenguaje verbal comprensible. Sin embargo, se reconoce que la fatiga asociada a su condición puede afectar su
atención | durante | periodos
prolongados de interacción con un dispositivo.

En el ámbito emocional, la valoración señala la presencia de un ánimo bajo, probablemente vinculado a sus limitaciones
funcionales | progresivas. | Esta
condición afecta su motivación y su nivel de participación social.
Los | registros | de | funciones
biológicas describen un estado emocional disminuido, lo que refuerza la necesidad de estrategias que faciliten la interacción social y la comunicación, ya que su dependencia en entornos sociales y laborales es considerable.
3. Análisis
de tareas El análisis de tareas consiste en identificar y describir todas las acciones que el usuario y el cuidador deben realizar para utilizar correctamente el prototipo. Este proceso permite reconocer las operaciones necesarias para su funcionamiento, detectar tareas críticas que podrían causar daño o
fallas | si | se | ejecutan
incorrectamente, y evaluar los riesgos asociados a cada una.

Es un paso fundamental para asegurar que el sistema sea seguro,
usable | y | adecuado | a | las
capacidades | del | usuario,
considerando su debilidad motora
generalizada, | fatiga | fácil | y
limitación severa del habla.
1. Lista de tareas:

Para iniciar el uso del prototipo, el usuario primero debe encender el módulo principal, lo que activa los servomotores y el sistema de control. Luego, debe abrir la aplicación móvil que acompaña al dispositivo. Esta app incluye un breve proceso de ajuste inicial para calibrar únicamente el reconocimiento de movimiento, permitiendo que el sistema interprete de manera precisa los gestos o acciones del usuario de acuerdo con su nivel de movilidad. Este proceso de calibración no afecta a los sensores físicos del prototipo, ya que ellos no requieren configuración por parte del usuario.

Una vez configurada la app, el usuario procede a seleccionar alguno de los botones que desea ejecutar (up, down, etc…). Durante la operación, el dispositivo ejecuta los movimientos mediante los servomotores.

Para finalizar, el usuario debe detener el dispositivo desde la aplicación seleccionando el botón de reinicio o desconectar el bluetooth. Finalmente, procede a apagar el módulo principal.

Tabla de tareas y evaluación de riesgos:

- Descripción de la tarea
- Responsable (usuario / cuidador)
- Tipo de tarea (normal / crítica)
- Riesgos asociados
- Justificación de criticidad

La información procede del análisis funcional del sistema y de la simulación práctica del prototipo desarrollada en el caso clínico.

2. Ta

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
s: Una de las tareas crít

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
o. E

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
a. A

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
o. S

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
a. 4. Criterios de éxito (requisito s de usabilida d)

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
## Tabla de Tareas y Evaluación de Riesgos

Resumen estructurado de tareas

Acción necesaria | Responsable | Naturaleza de la tarea | Riesgos posibles | Justificación
Verificar el estado del módulo y conectarlo a la fuente de energía | Cuidador | Crítica | Sobrecarga, desconexión accidental, fallo de inicio | Si se conecta incorrectamente, el dispositivo puede no funcionar o dañarse.
Colocar al usuario en una posición estable y segura | Cuidador | Crítica | Caídas, mala postura, dolor o fatiga excesiva | Una postura inadecuada afecta la precisión del uso y puede causar lesiones.
Encender el sistema y esperar la inicialización | Cuidador | Normal | Reinicios inesperados | Requiere supervisión mínima, no compromete la seguridad directa.
Ajustar la calibración del método de entrada (movimientos de cabeza) | Cuidador | Crítica | Movimientos no intencionales, activación incorrecta de comandos | Una calibración deficiente puede desencadenar reacciones peligrosas.
Activar o seleccionar comandos | Usuario | Crítica | | La condición motora y la disartria limitan la precisión, aumentando el

| | | Activación involuntaria de funciones | riesgo de errores.
Confirmar acciones del sistema (salidas, mensajes, movimientos asistidos) | Usuario | Normal | Interpretación incorrecta | No genera daño físico, pero puede causar errores en el uso.
Detener o apagar el sistema correctamente | Cuidador | Crítica | Apagado brusco, pérdida de datos, fallos posteriores | Un cierre incorrecto puede afectar la integridad del sistema y su seguridad.

## Tabla de métricas objetivos

Criterios | Definición | Indicador de éxito | Métrica objetivo | Método de evaluación
Eficacia | Evalúa qué tan bien el usuario logra realizar la acción principal del dispositivo (activar y desactivar los servomotores y manipular el joystick) | El usuario puede realizar la tarea por sí solo o con asistencia leve, manteniendo una ejecución natural y sin confusiones. | • Completar la acción principal (activar/desactivar) < 3 intentos. •Completar ciertas actividades diarias sin presentar fatiga • ≥ 80% de éxito en la tarea. | Observación directa durante pruebas supervisadas
Eficiencia | Tiempo y pasos necesarios para completar la tarea con fluidez. | El usuario completa la secuencia sin pausas prolongadas o pasos innecesarios. | • Tiempo de operación <2 minutos. | Cronometrado durante la sesión práctica
Satisfacción | Nivel de agrado, comodidad y confianza al usar el dispositivo. | El usuario expresa comodidad, percibe el funcionamiento como intuitivo y muestra disposición a volver a usarlo. | • ≥ 4/5 en facilidad de uso por parte del usuario. • ≥ 4/5 en facilidad de uso por parte del personal de salud / cuidador. | Encuesta posterior a la prueba al usuario y al personal de salud.
Seguridad | Evalúa si el dispositivo evita lesiones, molestias o esfuerzos innecesarios. | El usuario no presenta dolor, atrapamientos, tirones ni riesgo por movimientos no controlados del servomotor. | • 0 lesiones o molestias. • 0 fallas peligrosas del servomotor. • 0 fallas en la transmisión de la cámara. | Registros o comentarios del personal de salud, por medio de informes semanales o mensuales durante las primeras etapas de

| | | • 0 comentarios negativos por parte del cuidador o personal de la salud encargado. | implementación.
Confiabilidad | Funcionamiento estable de servomotores, sensores y sistema general. | El prototipo ejecuta las funciones sin fallas durante usos repetidos. | • ≥ 95% de funcionamiento estable en 10 ciclos de prueba. • Funcionamiento correcto del botón de emergencia o del modo cuando se desconecta el bluetooth > 5 intentos.
Accesibilidad | Facilidad de acceso físico y cognitivo a los controles (palanca asistida, interfaz simple). | El usuario puede alcanzar, sostener y accionar la palanca adaptada sin fuerza excesiva y con mínima asistencia. | • 100% de botones/controles accesibles en su rango de movilidad. • Los botones son claros y visibles para el usuario. | Validación visual y revisión con usuario.

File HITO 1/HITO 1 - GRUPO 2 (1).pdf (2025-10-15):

# EyePilot


Aplicación Móvil para Control de Silla de Ruedas Eléctrica con Eye-Tracking (Exteriores)

- Crosby Collantes, Alessandro Nicolas
- Rol: Líder, creación de app móvil “Wheelchair Eye Driving”
- Condori Pompilio, Pabel Mario
- Rol: Hardware
- Espinoza Padilla, Sebastian Amadeus
- Rol: Impresión 3D y materiales
- Fuentes Contreras, Arianna Fabiana del Valle
- Rol: Creación de app móvil “Cursor con Eye/Face Tracking”
- Cordova Palomino, Brandy Abigail
- Rol: Modelado 3D
- Fernandez García, Paola Andrea
- Rol: Montaje del sistema

Integrantes y roles:

# Análisis del Caso: Esclerosis Múltiple

Definición:
Enfermedad | autoinmune
crónica que afecta al Sistema
Nervioso | Central | | (médula
espinal, | cerebro | y | nervios
ópticos).
Aspecto | anatómico:
Daño a la vaina de mielina,
interrumpiendo | la | conducción
nerviosa.
Aspecto | fisiológico:
Alteración de la conducción saltatoria de los impulsos nerviosos, generando
déficit | neurológicos: | debilidad,
visión | borrosa, | problemas | de
equilibrio.

Datos relevantes:

- Mundial: 2.5 millones de personas.
- Perú: 9.12 casos / 100,000 habitantes.
- Demografía: 51.9% mujeres.
- Tipo dominante: remitente-recurrente (79.3%).
[1] Ministerio de Salud (MINSA). Esclerosis múltiple: la enfermedad que no debe pasar desapercibida. Plataforma del Estado Peruano. https://www.gob.pe/institucion/minsa/noticias/1178410-esclerosis-multiple-la-enfermedad-que-no-debe-pasar-desapercibida
[2] Ministerio de Salud (MINSA). Siete de cada 100 mil peruanos sufren de esclerosis múltiple. Plataforma del Estado Peruano. https://www.gob.pe/institucion/minsa/noticias/166106-siete-de-cada-100-mil-peruanos-sufren-de-esclerosis-multiple

# Análisis del Caso

La necesidad funcional primordial es la Movilidad y Seguridad mediante la Aplicación Móvil para Control de Silla de Ruedas Eléctrica con Eye-Tracking se justifica porque la naturaleza progresiva de la EM (debilidad 3/5 y fatiga fácil) agravará su dependencia en el traslado; el control por rastreo ocular ofrece la interfaz de acceso con el mínimo esfuerzo físico posible, maximizando su independencia en el transporte comunitario y reduciendo el riesgo de lesiones cutáneas o caídas asociadas a la dependencia en la Actividad de la Vida Diaria (AVD).

Necesidad funcional:
Movilidad y seguridad mediante aplicación móvil con control ocular (eye-tracking).

### Justificación:

- Esclerosis Múltiple avanzada con debilidad (3/5) y fatiga fácil.
- Limitación para usar mandos convencionales.
- Riesgo de caídas y lesiones por dependencia física.

### Impacto en la vida del usuario:

- Mejora la autonomía y desplazamiento independiente.
- Reduce la necesidad de asistencia familiar.
- Favorece la participación social y emocional.
- Aumenta la seguridad y la calidad de vida.
[3] National Multiple Sclerosis Society. Dysarthria in Multiple Sclerosis: Speech Problems. https://www.nationalmssociety.org/es/understanding-ms/what-is-ms/ms-symptoms/speech-problems

# Estado del Arte

Año de publicación y país: 2021 / Ecuador (Tesis de Grado)


Breve descripción y relación con el proyecto: El proyecto se enfoca en el diseño e implementación de un controlador electrónico económico, basado en la plataforma Arduino, para modernizar una silla de ruedas convencional y dotarla de funcionalidades de control remoto y monitoreo. La relación principal con un proyecto de investigación o desarrollo de prototipos radica en demostrar la viabilidad de bajo costo para mejorar la autonomía y seguridad de las personas con movilidad reducida, permitiendo el control directo por el usuario y la supervisión externa mediante tecnología móvil.

Características funcionales:

- Control Dual (Local y Remoto): Permite el manejo de la silla a través de un Mando Central Integrado (Joystick de efecto Hall, regulador de velocidad, pulsadores) para el control local, y un Control Remoto mediante una aplicación móvil Android, conectada vía Bluetooth, que replica las funciones de movimiento y regulación de velocidad.
- Ubicación y Seguridad (GSM/GPS): Incorpora un módulo SIM808 que habilita la función de Localización GPS (envío de coordenadas por SMS al tutor) y un Pulsador de Emergencia (Botón de pánico) en el mando central que notifica la ubicación en caso de imprevisto.
- Bloqueo de Funciones Remoto: Permite al tutor realizar el bloqueo de seguridad de las funciones de la silla de ruedas (con o sin reporte de coordenadas) desde la aplicación móvil.
- Funciones Periféricas: Incluye pulsadores dedicados en el mando central para la activación de la Bocina (Claxon) y el control de una Mesa Automática (apertura o cierre).
- Rendimiento Documentado: El prototipo alcanzó una autonomía de 14 horas y un rendimiento de 25 kilómetros.
[4] M. M. Olivo Arroyo y E. G. Gallegos Díaz, Diseño e implementación de un sistema de control electrónico de una silla de ruedas eléctrica con ubicación GPS y mando local o remoto a través de una aplicación celular (Android), para personas con discapacidad motriz reducida en miembros inferiores, Universidad Politécnica Salesiana, Guayaquil, Ecuador, 2018. [En línea]. Disponible en: https://dspace.ups.edu.ec/bitstream/123456789/16059/1/UPS-GT002280.pdf

# Estado del Arte

Título: Autonomous Wheelchair (US20170266069A1)
Año de publicación y país: 2017 / EEUU
Breve descripción y relación con el proyecto: Silla de ruedas inteligente con distintos modos de conducción (manual, semiautónomo y autónomo), equipada con un sistema que permite la interacción con dispositivos externos para recibir y recolectar datos del usuario, y un módulo de control central encargado de gestionar el desplazamiento y la seguridad. Incorpora interfaces como el joystick y el eye tracking, promoviendo una movilidad más precisa y fomentando la independencia del usuario.
Características funcionales:
- Sistema de interfaz de usuario permite la interacción mediante entradas manuales o sensoriales, integrando tecnologías como el joystick y el eye tracking para facilitar el manejo a personas con distintos niveles de movilidad.
- Sistema de comunicación emplea conexiones inalámbricas (Wi-Fi, Bluetooth y GPS) para enviar alertas, recibir comandos y compartir datos de localización o estado del usuario con dispositivos externos o personal de asistencia.


[5] M. Lozano y M. Arceo, «US20170266069A1 - Autonomous wheelchair - Google Patents», 15 de marzo de 2016. https://patents.google.com/patent/US20170266069A1/en

# Estado del Arte


Título: Wheelchair prototype controlled by position, speed and orientation using head movement
Año de publicación y país: 2022 / Colombia y Brasil
Breve descripción y relación con el proyecto: El estudio presenta un prototipo a escala que simula una silla de ruedas eléctrica controlada por movimientos de cabeza. Utiliza un sensor inercial (IMU) y control difuso para traducir la orientación del usuario en comandos de desplazamiento. El sistema integra sensores ultrasónicos, encoders y conectividad inalámbrica para navegación y monitoreo. Se evaluaron tres modos de control (manual, velocidad constante y variable), validando la precisión del sistema y su potencial aplicación en plataformas de movilidad asistida.
Características funcionales:
- Sistema de detección inercial (IMU)
- Control difuso (fuzzy logic)
- Sensores ultrasónicos
- Encoders ópticos
- Comunicación inalámbrica


[6] A. X. González-Cely, M. Callejas-Cuervo, y T. Bastos-Filho, «Wheelchair prototype controlled by position, speed and orientation using head movement», HardwareX, vol. 11, p. e00306, abr. 2022, doi: 10.1016/j.ohx.2022.e00306.


EyeGaze Edge / Eyegaze Systems - Eye-gaze systems para comunicación

- Responsable: Eyegaze Systems Ltd. (proveedor especializado).
- Descripción funcional: Sistemas de eye-gaze dedicados para control de PC, comunicación y domótica; compensan fatiga ocular y permiten baja carga motora
- Ventajas: Especialización en usuarios con fatiga; interfaz de bajo esfuerzo; integración con control ambiental.
- Desventajas: Costo, y rendimiento decrece si hay problemas oculomotores (nistagmo, diplopía); puede requerir ajustes frecuentes.


Permobil (F5) — Sillas de ruedas eléctricas avanzadas

- Responsable: Permobil (empresa).
- Descripción funcional: Sillas eléctricas con elevación de asiento, recline/tilt, suspensión avanzada, opciones de control alternativo (joystick, control por switch, interfaces externos). Modelos pensados para confort y prevención de complicaciones (presión)
- Ventajas: Mejora autonomía de desplazamiento; funciones posturales (tilt/recline/elevación) ayudan a prevenir úlceras y facilitan transferencias; integrables con sistemas de control alternativo.
- Desventajas: Alto costo de adquisición y mantenimiento; necesitan adaptación ergonómica especializada; tamaño puede dificultar maniobra en viviendas con barreras arquitectónicas.

# Estado del Arte

[7] Eyegaze Inc., “Eyegaze Edge,” Eyegaze. [Online]. Available: https://eyegaze.com/products/eyegaze-edge/. | [8] Permobil, “Home,” Permobil. [Online]. Available: https://www.permobil.com/en-us.

# Metodología VDI

Aplicación Móvil para Control de Silla de Ruedas Eléctrica con Eye-Tracking: Una aplicación móvil puede mejorar la calidad de vida del usuario con movilidad reducida, facilitando el control de la silla de ruedas. El objetivo de este proyecto es diseñar un prototipo de sistema de control inalámbrico basado en Android que permita manejar una silla de ruedas eléctrica de forma remota, integrando un sistema de eye-tracking y actuadores (servomotor) para aumentar la autonomía del usuario.

ID | Requisito Funcional | Prioridad | Justificación
RF1 | El sistema debe captar y procesar señales oculares del usuario para convertirlas
en un cursor o coordenada de mirada. | E
| | | Es la función central para la operación de la silla.
RF2 | El sistema debe permitir al usuario controlar comandos de movimiento (adelante, atrás, izquierda, derecha, detener) mediante la señal ocular. | E | Sin esto, el sistema no puede dirigir la silla.
RF3 | El sistema debe transmitir el comando de movimiento generado al microcontrolador (ESP32) de forma inalámbrica (Bluetooth) o por cable (USB). | E | Necesario para que el microcontrolador reciba la instrucción.
RF4 | El microcontrolador debe interpretar el comando de movimiento y generar las señales de control adecuadas para los servomotores. | E | Proceso indispensable para convertir la orden en acción.
RF5 | El sistema debe accionar un mecanismo (brazo robótico/servomotor) que mueva el joystick de la silla de ruedas según el comando recibido. | E | La acción física que produce el movimiento de la silla.
RF6 | El sistema debe controlar el movimiento de la silla de ruedas eléctrica de forma precisa según la dirección ordenada. | E | El objetivo principal del sistema.
RF7 | El sistema debe utilizar sensores ultrasónicos para detectar y medir la distancia de obstáculos en el entorno. | E | Crítico para la seguridad y evitar colisiones.
RF8 | El sistema debe corregir la trayectoria o detener el movimiento de la silla de forma automática cuando se detecte un peligro (obstáculo cercano). | E | Requisito de seguridad vital para el usuario.
RF9 | El sistema debe mostrar en la aplicación (app) el estado del sistema, incluyendo modo activo, nivel de batería y advertencias de obstáculos. | I | Fundamental para la usabilidad y la toma de decisiones del usuario.
RF10 | El sistema debe proporcionar retroalimentación visual o auditiva al usuario sobre el estado del sistema y la detección de obstáculos. | I | Mejora la interacción y la conciencia situacional.
ID | Requisitos no funcionales | Prioridad | Justificación
RNF1 | Seguridad: El sistema debe garantizar que el movimiento de la silla se detenga inmediatamente en caso de fallo crítico de los sensores u otros componentes. | E | La seguridad física del usuario es la máxima prioridad.
RNF2 | Rendimiento: El tiempo de respuesta desde la captura de la señal ocular hasta el inicio de la ejecución del movimiento debe ser mínimo para una operación fluida y segura. | E | La latencia afecta directamente la seguridad y el control.
RNF3 | Fiabilidad: El sistema de control y detección de obstáculos debe operar de manera consistente y precisa en diversas condiciones de iluminación y entorno. | E | La inconsistencia en el control o detección puede ser peligrosa.
RNF4 | Usabilidad: La interfaz de usuario (App) debe ser intuitiva, con un tiempo de aprendizaje mínimo para los comandos esenciales. | I | Facilita el uso a personas con discapacidad.
RNF5 | Usabilidad: La retroalimentación visual y auditiva debe ser clara y no intrusiva para el usuario. | I | Contribuye a una buena experiencia de usuario.
RNF6 | Rendimiento: El consumo de energía del sistema debe permitir una autonomía de uso mínima aceptable para el usuario (ej. 8 horas de uso continuo). | I | Afecta la utilidad y autonomía del usuario.
RNF7 | Mantenibilidad: El código del software debe estar modularizado y documentado para permitir futuras actualizaciones o correcciones. | D | Facilita la evolución y el soporte a largo plazo.
RNF8 | Portabilidad: La aplicación de control debe ser compatible con los sistemas operativos móviles más comunes (iOS/Android). | D | Amplía el mercado potencial de usuarios.

Tabla N°1: Requisitos no funcionales y funcionales y su clasificación

# Metodología VDI: Caja Negra


# Metodología VDI: Esquema de funciones



# Metodología VDI: Matriz morfológica

Tabla N°2: Matriz morfológica

# Metodología VDI: Tabla de Valoración


0 = No satisface

1 = Aceptable a las justas

2 = Suficiente

3 = Bien

4 = Muy bien

Tabla N°3: Tabla de valoración


# Metodología VDI: Boceto de Wheelchair Control App

PIEZA | NOMBRE | MATERIAL
1 | Celular | Android
2 | Aplicación de Control | "Weelchair Control App" (Software)

ajustable; PIEZA; NOMBRE; MATERIAL

# Metodología VDI: Boceto de caja maestra y mano electrónica con localizador

1 | Caja Maestra (Carcasa) | Plástico (e.g., PLA para impresión 3D o ABS), componentes (ESP 32, Batería de Li-ion, cables de conexión)
2 | Servomotor (o motor de la mano) | Metal, plástico, componentes electrónicos
3 | Mano Electrónica (Estructura) | Plástico (PLA para impresión 3D o ABS), localizador ajustable (plástico o metal ligero)

# Conclusiones/siguientes pasos

- Viabilidad Técnica: La integración de eye-tracking con control de silla de ruedas es viable mediante tecnologías accesibles y no invasivas.
- Solución Centrada en el Usuario: Aborda la movilidad y seguridad en Esclerosis Múltiple,
minimizando | esfuerzo | físico | y | maximizando
autonomía.
- | Seguridad | como | Prioridad: | Diseñado | con
mecanismos de detección, detección de obstáculos y
retroalimentación visual/auditiva.
- Diseño Modular y Escalable: Facilita mejoras futuras
y adaptación a distintas necesidades del usuario. | 1. | Prototipado

### 2. Implementación de Hardware

### 3. Pruebas y validación

## 4. Iteración y mejora

- Desarrollo de la app
- Integración con sistema de seguimiento ocular.
- Ensamblaje de microcontrolador, servomotor y sensores.
- Conexión inalámbrica app-controlador.
- Evaluación de respuesta, precisión y usabilidad.
- Pruebas con usuarios potenciales.
- Optimización de interfaz y consumo energético.
- Ajustes según retroalimentación.

# Referencias Bibliográficas

[1] Ministerio de Salud (MINSA). Esclerosis múltiple: la enfermedad que no debe pasar desapercibida. Plataforma del Estado Peruano. https://www.gob.pe/institucion/minsa/noticias/1178410-esclerosis-multiple-la-enfermedad-que-no-debe-pasar-desapercibida
[2] Ministerio de Salud (MINSA). Siete de cada 100 mil peruanos sufren de esclerosis múltiple. Plataforma del Estado Peruano. https://www.gob.pe/institucion/minsa/noticias/166106-siete-de-cada-100-mil-peruanos-sufren-de-esclerosis-multiple
[3] National Multiple Sclerosis Society. Dysarthria in Multiple Sclerosis: Speech Problems. https://www.nationalmssociety.org/es/understanding-ms/what-is-ms/ms-symptoms/speech-problems
[4] M. M. Olivo Arroyo y E. G. Gallegos Díaz, Diseño e implementación de un sistema de control electrónico de una silla de ruedas eléctrica con ubicación GPS y mando local o remoto a través de una aplicación celular (Android), para personas con discapacidad motriz reducida en miembros inferiores, Universidad Politécnica Salesiana, Guayaquil, Ecuador, 2018. [En línea]. Disponible en: https://dspace.ups.edu.ec/bitstream/123456789/16059/1/UPS-GT002280.pdf
[5] M. Lozano y M. Arceo, «US20170266069A1 - Autonomous wheelchair - Google Patents», 15 de marzo de 2016. https://patents.google.com/patent/US20170266069A1/en
[6] A. X. González-Cely, M. Callejas-Cuervo, y T. Bastos-Filho, «Wheelchair prototype controlled by position, speed and orientation using head movement», HardwareX, vol. 11, p. e00306, abr. 2022, doi: 10.1016/j.ohx.2022.e00306.
[7] Eyegaze Inc., “Eyegaze Edge,” Eyegaze. [Online]. Available: https://eyegaze.com/products/eyegaze-edge/
[8] Permobil, “Home,” Permobil. [Online]. Available: https://www.permobil.com/en-us


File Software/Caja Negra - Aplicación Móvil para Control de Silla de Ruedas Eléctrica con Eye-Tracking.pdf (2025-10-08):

# Metodologia de diseño

Captar y procesar señales oculares; Controlar comandos; Transmitir comando al controlador; Detectar obstáculos; Retroalimentar al usuario; Corregir o detener movimiento; Interpretar y ejecutar comando; Controlar movimiento de la silla; Salidas; Movimiento controlado de la silla de ruedas.; Registro y almacenamiento de datos operativos; Retroalimentación visual y auditiva al usuario; Energía; Información; Entradas


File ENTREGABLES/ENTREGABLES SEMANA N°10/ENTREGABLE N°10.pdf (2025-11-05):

Entregable N°10:

Prototipado electrónico 2. Animación 3D y fabricación digital de componentes. Plan de usabilidad basado en evidencias.

Autores:

Alessandro Nicolas Crosby Collantes

Pabel Mario Condori Pompilio

Arianna Fabiana Del Valle Fuentes Contreras

Paola Andrea Fernández García

Brandy Abigail Cordova Palomino

Sebastián Amadeus Espinoza Padilla

Asesores:

Miguel Rogger Hoyos Alvitez

Marco Mugaburu Celi

Shirley Pahuachon Nuñez

Curso:

Fundamentos de Biodiseño – Ciclo IV

Universidad Peruana Cayetano Heredia

Facultad de Ciencias e Ingeniería

Octubre 2025

### 1. PLANOS PARA IMPRESIÓN 3D

Pieza Soportes localizadores - Menor:

https://cad.onshape.com/documents/edb97f12d21e749d59034de8/w/99f2d6cddf152d24a7fdb7b9/e/abc29e0f48e1030422e92dec


Pieza Soportes localizadores - Medio:

https://cad.onshape.com/documents/b639f0d290363062dea46fee/w/1b7bff4be1a3968861d8bbc7/e/c23ae93cd41583b7b3b8c063


Pieza Soportes localizadores - Mayor:

https://cad.onshape.com/documents/2dee9571cd133ef82f8955e2/w/1da2e4b7f9bcbd67be0db328/e/274fafe3c13b19e830e85cad


Base de la Mano Electrónica:

https://cad.onshape.com/documents/377a0465ed2f3304d1fbda1b/w/c021ed7d895b711a3254a26a/e/38853d71ee1a57854fb5d3c7


Partes de la Mano Electrònica - Parte 1:

https://cad.onshape.com/documents/0de5ccb813b30a7ee5c2265f/w/57f83e18a7c7bfe297b4f0bf/e/b82d7e7db424f0d85b1dd524


Partes de la Mano Electrònica - Parte 2:

https://cad.onshape.com/documents/f155cdb71a3b22ea513251c9/w/3f009edcc30d1d8eb7719015/e/982696bff2c351be53e56836


Partes de la Mano Electrònica - Parte 3:

https://cad.onshape.com/documents/25f1c4799bb46443a9267e30/w/8d47ccf09fee25b7c332eb4e/e/7dba531bffbf7b67e8bd046d


Partes de la Mano Electrònica - Parte Servo 1:

https://cad.onshape.com/documents/15074d87b95f3e618a6b4de7/w/519aacf304bf6f46dd682ed2/e/b6fd2a8d963e8cbb42c56351


Partes de la Mano Electrònica - Parte Servo 2:

https://cad.onshape.com/documents/570ace84528bac353de55933/w/ef241a936cd0af84132f863b/e/dc5f7256e8f30802bc5d8af5


### 2. PROTOTIPADO ELECTRÓNICO

### 2.1 Código del prototipado


### 2.2 Imágenes del prototipado

En la siguiente imágen simulamos el joystick virtual de la aplicación con un joystick analógico, los microservomotores usados son sólo de referencia, el ARDUINO UNO será reemplazado por un ESP32, la fuente de poder solo es usada para el prototipado


Vídeo del funcionamiento: https://youtube.com/shorts/OhZxIiCbmYA

En las siguientes imágenes se visualiza oomo vamos a energizar nuestro prototipo:


El primer valor de voltaje medido por el multímetro viene a ser el de la batería:


El segundo valor de voltaje medido por el multímetro viene a ser el del boost:


### 3. MODELADO 3D FINAL


https://cad.onshape.com/documents/f80c77bf9b6a820f8546ec3a/w/fcd60c46b07f40aeb51dcd97/e/ee2be1f5c0e253c33ff10314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 0ad4aab416549b7961d52b (https://cad.onshape.com/documents/f80c77bf9b6a820f8546ec3a/w/fcd60c46b07f40aeb51dcd97/e/ee2be1f5c0e253c33ff10314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)

TABLA 1: Plan de usabilidad basado en la evidencia

Sección del plan | ¿Qué es? | ¿Qué hacer? | ¿Qué evidencia deben incluir?


1. Contexto
de uso | El prototipo será utilizado por personas que padecen de esclerosis múltiple avanzada las cuales presentan discapacidad motriz severa, pero mantienen el control ocular y cognitivo suficiente para manejar el dispositivo. Este consiste en controlar una silla de ruedas eléctrica mediante movimientos oculares detectados por una app Android con eye-tracking, que envía comandos vía Bluetooth al ESP32, el cual acciona dos servomotores que mueven el joystick.
| Por otro lado, en cuanto su uso se realizará en entornos exteriores controlados y clínicas de rehabilitación, bajo supervisión inicial de un terapeuta. El sistema busca mejorar la autonomía y seguridad del usuario, integrando sensores ultrasónicos y botón de parada de emergencia para prevenir accidentes.

El prototipo está diseñado principalmente para pacientes con esclerosis múltiple avanzada, quienes presentan discapacidad motriz severa, pero conservan control ocular y cognitivo. Asimismo, el terapeuta o cuidador actúa como usuario secundario, puesto que este debe encargarse de configurar y supervisar el funcionamiento del sistema en todo momento, garantizando la correcta interacción del paciente con la silla de ruedas.

Por otro lado, el uso del prototipo debe realizarse en entornos controlados, como hospitales, clínicas de rehabilitación y zonas exteriores seguras, donde las condiciones físicas y técnicas permiten un manejo confiable del equipo. Sin embargo, no se recomienda su uso en exteriores con múltiples factores externos (automóviles o lugares concurridos), ya que se requieren programas y sensores adicionales que aseguren la seguridad e integridad del paciente frente a obstáculos o interferencias múltiples [1].

En cuanto a la frecuencia de uso, esta depende del estado físico del paciente y del plan de rehabilitación propuesto, entonces las sesiones diarias podrían ser progresivas 10, 20, 30 a 60 minutos, lo que permite que el usuario practique y mejore su autonomía de manera progresiva, mientras se garantiza su seguridad mediante sensores y un botón de parada de emergencia.

2. Perfil del
usuario

El perfil del usuario describe las características físicas, cognitivas y emocionales de la persona que utilizará el dispositivo, en este caso, un hombre de 52 años con diagnóstico de Esclerosis Múltiple Avanzada y disartria severa.

Características físicas:

- Debilidad muscular generalizada (3/5 en escala de fuerza muscular).
- Fatiga fácil con esfuerzo físico moderado.
- Control parcial de micción e intestino.
- Apetito conservado.
- Emisión verbal ininteligible, con habla limitada.

Características cognitivas:

- Estado de conciencia lúcido.
- Comprensión de órdenes simples y complejas conservadas.
- Capacidad de responder mediante gestos o medios no verbales.
- Dificultad para la comunicación oral, pero conserva la comprensión.

Características emocionales:

- Ánimo bajo, posiblemente relacionado con la limitación funcional y la dependencia.
- Necesidad de mantener participación social y emocional.
- Dependencia en contextos sociales y laborales para la comunicación.

Analizar si el usuario tiene limitaciones visuales, motoras, cognitivas o de comprensión mediante:

Evaluación de limitaciones motoras: Verificar capacidad de movimiento, fuerza muscular y coordinación para manipular dispositivos. En el caso del usuario con EM avanzada, se evidencia debilidad generalizada (3/5) y fatiga fácil, lo que dificulta realizar movimientos finos o sostenidos.

Evaluación de limitaciones visuales: Determinar agudeza visual, sensibilidad al contraste y capacidad de enfoque. Aunque no se reportan problemas visuales específicos en el caso, la EM puede asociarse con visión borrosa o nistagmo, por lo que se requiere contraste alto y elementos visuales grandes.

Evaluación de limitaciones cognitivas: Analizar memoria, atención y capacidad de procesamiento. El usuario mantiene estado consciente y comprensión de órdenes complejas, pero la fatiga puede afectar su concentración durante uso prolongado.

Evaluación de limitaciones de comprensión: Verificar comprensión de lenguaje oral, escrito y simbólico. El usuario comprende órdenes pero tiene emisión verbal ininteligible, por lo que requiere sistemas de comunicación aumentativa con retroalimentación visual clara.

Evidencia | incluida | (Datos | del | caso
seleccionado):

❖ Limitaciones Motoras:

Característica: Debilidad generalizada y fatiga fácil que afecta la interacción física con el dispositivo.

Evidencia: Del examen clínico: "Motricidad: debilidad generalizada (3/5), fatiga fácil."

❖ Capacidades | Cognitivas | y | de
Comprensión:

Característica: Comprensión de órdenes simples
y | complejas | conservada; | capacidad | de
comunicación mediante gestos.

Evidencia: Del examen clínico: "Estado de conciencia: lúcido, comprende órdenes simples y complejas. Lenguaje: emisión verbal ininteligible, comunicación limitada." Y de la funcionalidad inicial: "Puede comprender y responder con gestos."

❖ Estado Emocional:

Característica: Ánimo bajo.

Evidencia: De las funciones biológicas: "Ánimo bajo."

❖ Necesidad Comunicativa Principal:

| | | Característica: Gran limitación en la comunicación oral, dependiente de sistemas alternativos. Evidencia: Del diagnóstico y la funcionalidad inicial: "Disartria severa y pérdida parcial del habla en paciente con EM avanzada.", "Gran limitación en la comunicación oral."
3. Análisis de tareas | Es el proceso mediante el cual se identifican y describen las acciones necesarias para que el usuario y el cuidador utilicen correctamente el prototipo. Permite determinar las tareas que se deben realizar para su funcionamiento, reconocer las tareas críticas que podrían generar daño o error, y evaluar los riesgos asociados a cada una. [4], [5]. | Listar todas las tareas que el usuario y el cuidador deben ejecutar para poner en marcha, operar y apagar el sistema (por ejemplo, encender el módulo, calibrar el eye-tracking, seleccionar comandos, activar sensores y detener la silla). Identificar aquellas tareas críticas cuya ejecución incorrecta podría comprometer la seguridad del usuario o el funcionamiento del dispositivo. [4], [6]. | Tabla de tareas y riesgos; justificación de criticidad. Evidencia incluida: Tabla que describe cada tarea, su tipo, los posibles riesgos asociados y una breve justificación de por qué se considera crítica. Esta información se obtuvo del análisis funcional del sistema y de la simulación práctica del uso del prototipo [1], [2].
4. Criterios de éxito (requisitos de usabilidad) | Son los indicadores concretos que permiten evaluar si el sistema es fácil, seguro y eficiente de usar. Estos criterios miden el desempeño del usuario (eficacia y eficiencia), su nivel de satisfacción y la seguridad del dispositivo durante las pruebas [4], [5], [6]. | Definir objetivos cuantificables para cada criterio de usabilidad: ● Eficacia: porcentaje de tareas completadas correctamente. ● Eficiencia: tiempo requerido para ejecutar las tareas. ● Satisfacción: percepción del usuario sobre comodidad y facilidad de uso. ● Seguridad: cantidad de errores o incidentes durante la prueba [6], [7]. | Tabla de métricas objetivo. Evidencia incluida: Resultados de pruebas de usabilidad con usuarios, cronometraje del tiempo de operación, encuestas SUS (System Usability Scale) y registro de incidentes. Estas métricas permiten verificar la facilidad, seguridad y confiabilidad del sistema [5], [6].

### Tabla de tareas y riesgos

Tarea | Descripción | Tipo de tarea | Riesgo asociado | Justificación de criticidad
Encendido del sistema | El cuidador enciende la caja maestra (ESP32) y verifica la conexión Bluetooth con la App. | Inicial / Configuración | Falla de conexión o sobrecalentamiento. | Sin conexión, el sistema no puede operar correctamente [2].
Calibración del eye-tracking | El usuario fija la mirada para calibrar el rastreador ocular antes del uso. | Configuración | Error en la detección del ojo o calibración imprecisa. | Un error de calibración puede generar movimientos no deseados de la silla [1].
Selección de comandos | El usuario selecciona con la mirada los botones de movimiento (adelante, izquierda, derecha, detener). | Operativa crítica | Activación involuntaria o errónea del comando. | Puede generar desplazamientos imprevistos o colisiones [2].
Activación de sensores ultrasónicos | El sistema detecta obstáculos y detiene el movimiento automáticamente. | Automática / Seguridad | Desalineación o interferencia del sensor. | Si no detecta obstáculos, puede ocurrir un accidente [2].
Uso del botón de emergencia | El cuidador o usuario presiona el botón físico para detener la silla. | Emergencia | Retardo o fallo del sistema ante la orden. | Es la función principal de seguridad ante fallos de software o hardware [7].
Apagado del sistema | El cuidador apaga la caja maestra y cierra la aplicación. | Finalización | Apagado incorrecto o pérdida de configuración. | Un apagado inadecuado puede dañar el hardware o corromper datos [5].

### Tabla de métricas objetivo

Criterio | Indicador de éxito | Métrica objetivo | Método de evaluación
Eficacia | Porcentaje de tareas realizadas correctamente (conexión, control, parada). | ≥ 95 % de tareas completadas sin error. | Observación directa durante pruebas supervisadas [5].
Eficiencia | Tiempo promedio desde encendido hasta la ejecución del primer movimiento. | < 2 minutos. | Cronometrado durante la sesión práctica [5].
Satisfacción | Percepción de facilidad y confort en el uso. | SUS ≥ 70. | Encuesta posterior a la prueba [6].
Seguridad | Número de colisiones o fallos críticos. | 0 incidentes por sesión. | Registro de bitácora de pruebas [2].
Confiabilidad | Tiempo de operación continua sin reinicios o bloqueos. | ≥ 60 minutos. | Prueba de estabilidad en laboratorio [2].
Accesibilidad | Diseño visual claro y elementos grandes para usuarios con limitaciones visuales. | Contraste > 70 %, iconos ≥ 1.5 cm. | Validación visual y revisión con usuario [1].

## Bibliografía

[1] C. Ferrín-Bolaños et al., «Interfaz humano-computador basada en gestos faciales y orientada a la aplicación WhatsApp para personas con limitación motriz de miembros superiores», TecnoLógicas, vol. 24, n.o 50, p. e1722, ene. 2021, doi: 10.22430/22565337.1722.
[2] J. M. Córdova, “Diseño de una silla de ruedas eléctrica controlada por voz para personas con discapacidad motriz,” Universidad Politécnica Salesiana, Guayaquil, Ecuador, 2018. [Online]. Available: https://dspace.ups.edu.ec/bitstream/123456789/16059/1/UPS-GT002280.pdf
[3] | World | Health | Organization, | “Disability | and | health,” | WHO | Fact | Sheets, | Oct. | 2022. | [Online]. | Available:
https://www.who.int/news-room/fact-sheets/detail/disability-and-health
[4] D. A. Norman, The Design of Everyday Things, Rev. and expanded ed. New York: Basic Books, 2013.
[5] J. Nielsen, Usability Engineering. San Francisco: Academic Press, 1994.
[6] J. Brooke, “SUS: A quick and dirty usability scale,” in Usability Evaluation in Industry, P. W. Jordan, B. Thomas, B. A. Weerdmeester, and I. L. McClelland, Eds. London: Taylor & Francis, 1996, pp. 189–194.
[7] International Organization for Standardization, ISO 9241-210: Ergonomics of Human-System Interaction – Part 210: Human-Centred Design for Interactive Systems, Geneva, Switzerland: ISO, 2018.

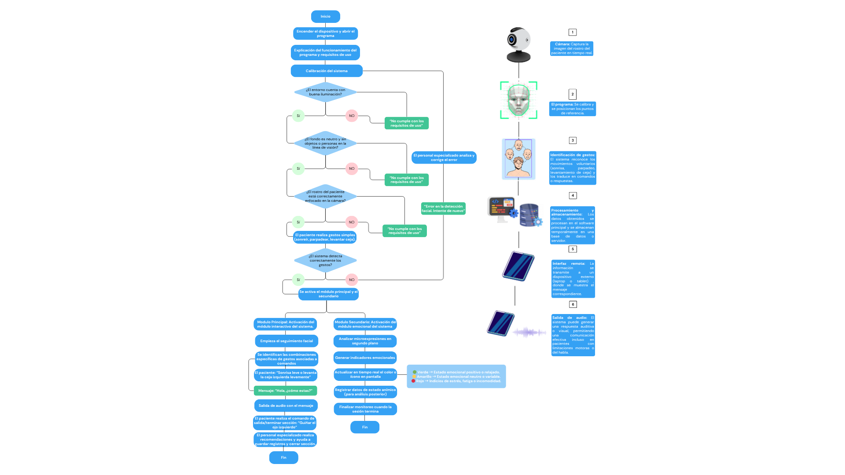
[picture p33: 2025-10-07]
Software/Diagrama de Flujo - Aplicación de Escritorio para Monitoreo de Emociones y mensajes a partir de gestos faciales. .png

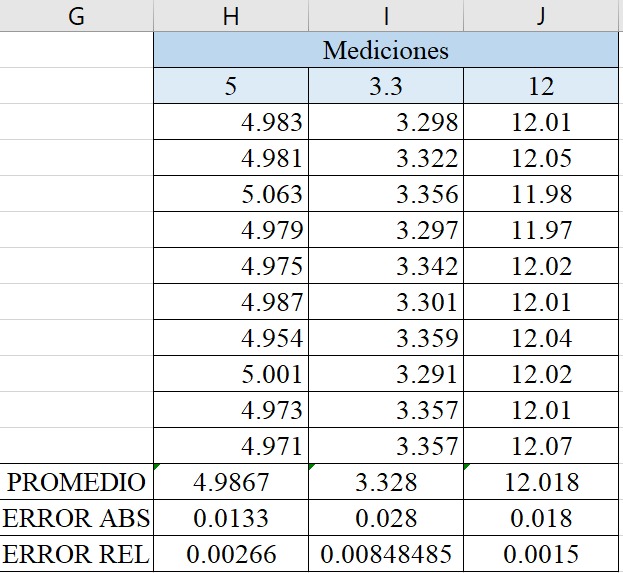
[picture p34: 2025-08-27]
TALLERES/TALLERES SEMANA N°2/T1 - Entregable 2.jpg

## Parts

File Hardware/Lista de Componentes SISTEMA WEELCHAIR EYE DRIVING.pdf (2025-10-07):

## Lista de Componentes – Sistema Weelchair Eye Driving

(1 caja maestra, 1 mano electónica y 1localizador ajustable)

1. Piezas impresas en 3D para la caja donde irán los componentes (placa base, tapa, dos sujetadores de cable) → S/ variable
2. Piezas impresas en 3D para brazo robótico (pieza base, soporte de servo X, anillo inferior, soporte de servo Y, anillo superior, brazo de transmisión) → S/ variable
3. Manguito de joystick impreso en 3D (diámetro interno ajustado al eje del joystick) → S/ variable
4. Piezas impresas en 3D para la placa ajustable (locator plate) (anillo inferior, anillo superior, anillo de retención) → S/ variable
5. ESP32 DevKit V1 → S/ 29 – 77
6. Micro servos Turnigy 380Max (o similar, alto torque) – 2 unidades → S/ 72 c/u (total S/ 144)
7. Brazos metálicos de servo 25T – Modelo específico: 25T metal servo arm → S/ 6
8. Módulo Relay Shield 4 canales – Modelo específico: 4 Channel Relay Shield → S/ 34
9. Módulo Servo/Sensor Shield – Modelo específico: Servo/Sensor Shield → S/ 24
10. Cable USB A a USB B (longitud según necesidad) → S/ 7
11. Cable USB A a plug DC (el tipo de plug no importa, será retirado) → S/ 7
12. 3 conectores jack 3.5 mm mono pre-cableados (cortados de extensiones o splitters) → S/ variable
13. 2 cables de extensión de servo (macho a hembra) (longitud según necesidad) → S/ 10
14. 20 tornillos No.6 Pan Head, Pozi, autorroscantes 13mm → S/ 5
15. 10 tornillos No.6 Pan Head, Pozi, autorroscantes 16mm → S/ 5
16. 10 tornillos No.6 Pan Head, Pozi, autorroscantes 6mm → S/ 5
17. 10 pernos M3 avellanados, Pozi → S/ 5
18. 10 tuercas M3 Nyloc → S/ 5
19. 10 arandelas planas M3 → S/ 7
20. Cinta autoadhesiva de gancho y felpa (Velcro) 20 mm de ancho, 60 cm de cada lado → S/ 13
21. Super Glue (adhesivo instantáneo) → S/ 10
22. Cinta de espuma adhesiva de doble cara (5 o 10 mm de ancho, o cortada de un rollo más ancho) → S/ 12
23. Fuente de alimentación para servos 5–6V, 1A mínimo (No usar USB de PC. Se puede usar batería o cargador de auto USB conectado a batería principal de la silla de ruedas. Las power banks NO son recomendadas por apagarse automáticamente. Los portapilas de 4 x AA con salida USB sí son adecuados, así como packs recargables con interruptor on/off).

Modelos específicos:

- 4 x AA Battery Holder with USB out
- 5V/12V Battery Pack

El costo aproximado total (sin contar los elementos "variables" como piezas impresas en 3D y conectores) está entre:

- Mínimo: S/ 328
- Máximo: S/ 376

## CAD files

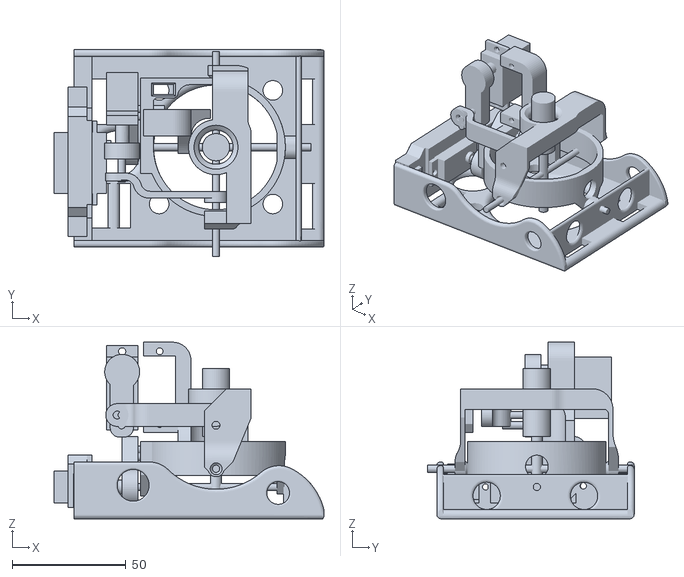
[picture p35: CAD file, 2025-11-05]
Hardware/Autodesk 123 Design Files for Eyedrivomatic/Mano Electrónica STL.stl
118.8 x 90.8 x 77.7

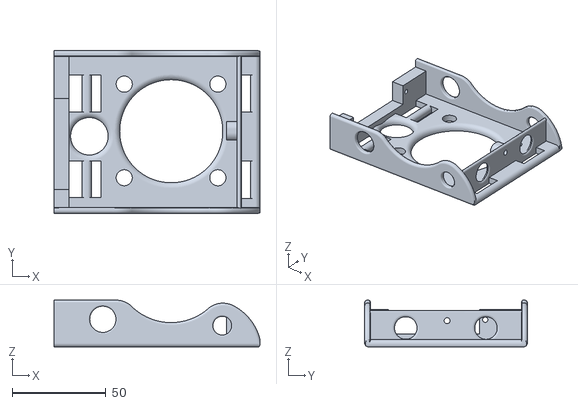
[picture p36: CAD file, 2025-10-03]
Hardware/STL Files for 3D Printing/Base de la mano electrónica.stl
110.0 x 86.9 x 25.0

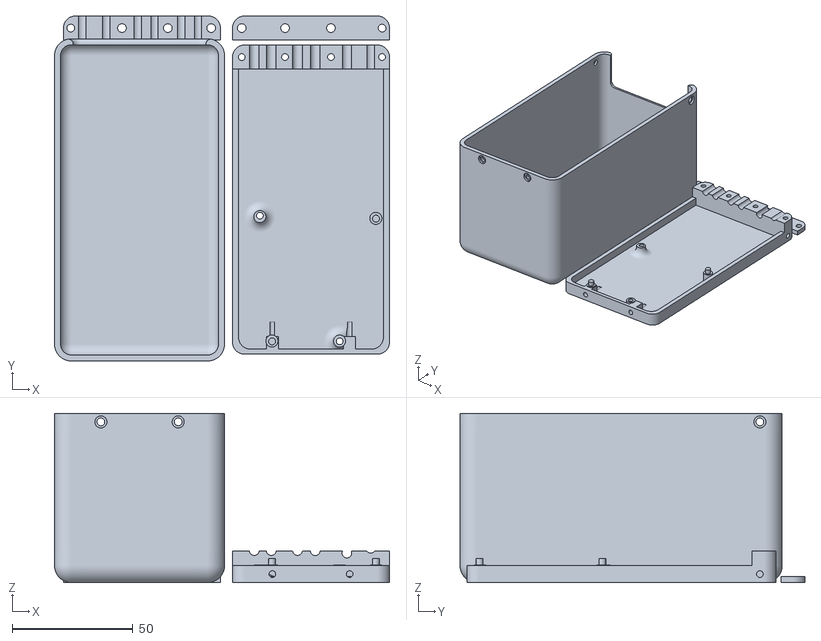
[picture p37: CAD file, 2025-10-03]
Hardware/STL Files for 3D Printing/Caja maestra.stl
138.7 x 142.8 x 70.0

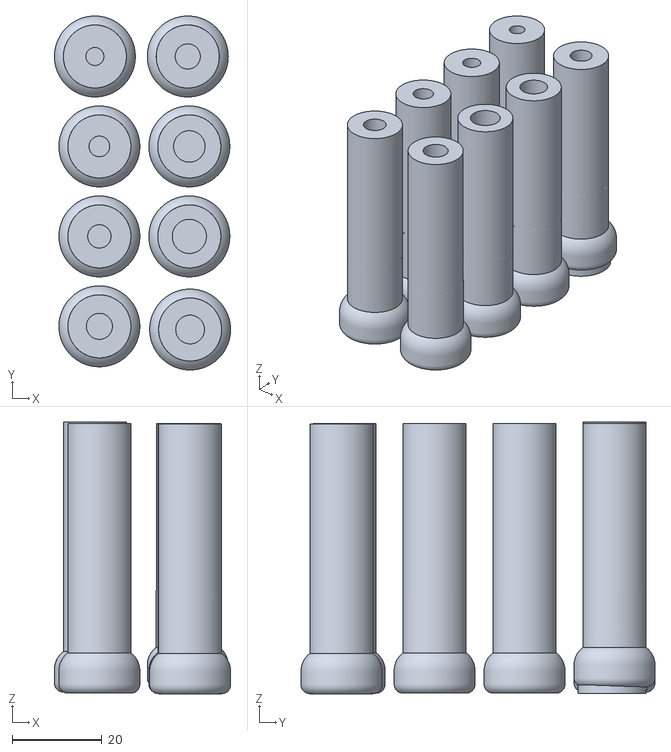
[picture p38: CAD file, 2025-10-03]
Hardware/STL Files for 3D Printing/Fundas para el joystick de la silla.stl
39.2 x 78.7 x 60.4

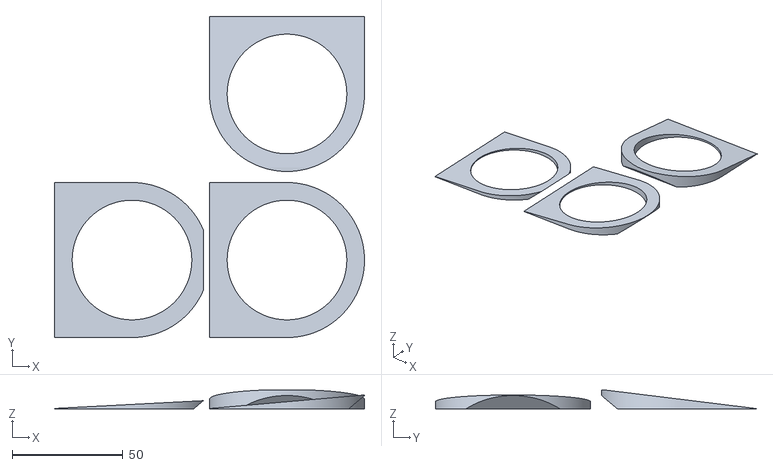
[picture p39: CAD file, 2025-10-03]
Hardware/STL Files for 3D Printing/Widgets de nivelación de la placa.stl
140.0 x 145.0 x 8.50

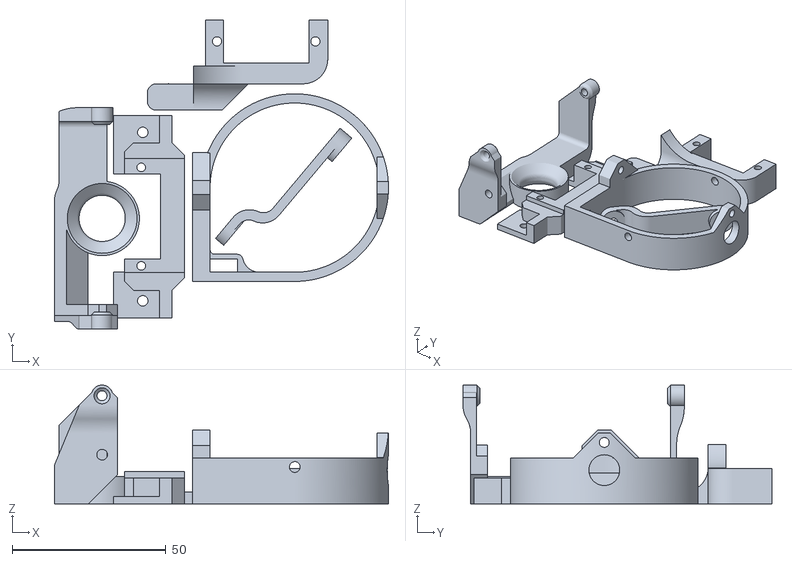
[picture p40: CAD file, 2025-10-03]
Hardware/STL Files for 3D Printing/Partes de la mano electrónica.stl
108.6 x 100.5 x 38.7

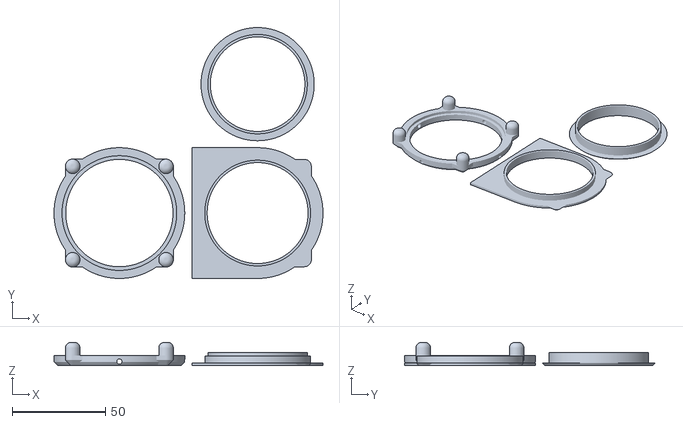
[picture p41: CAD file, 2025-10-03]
Hardware/STL Files for 3D Printing/Placa localizadora.stl
144.0 x 134.3 x 12.5

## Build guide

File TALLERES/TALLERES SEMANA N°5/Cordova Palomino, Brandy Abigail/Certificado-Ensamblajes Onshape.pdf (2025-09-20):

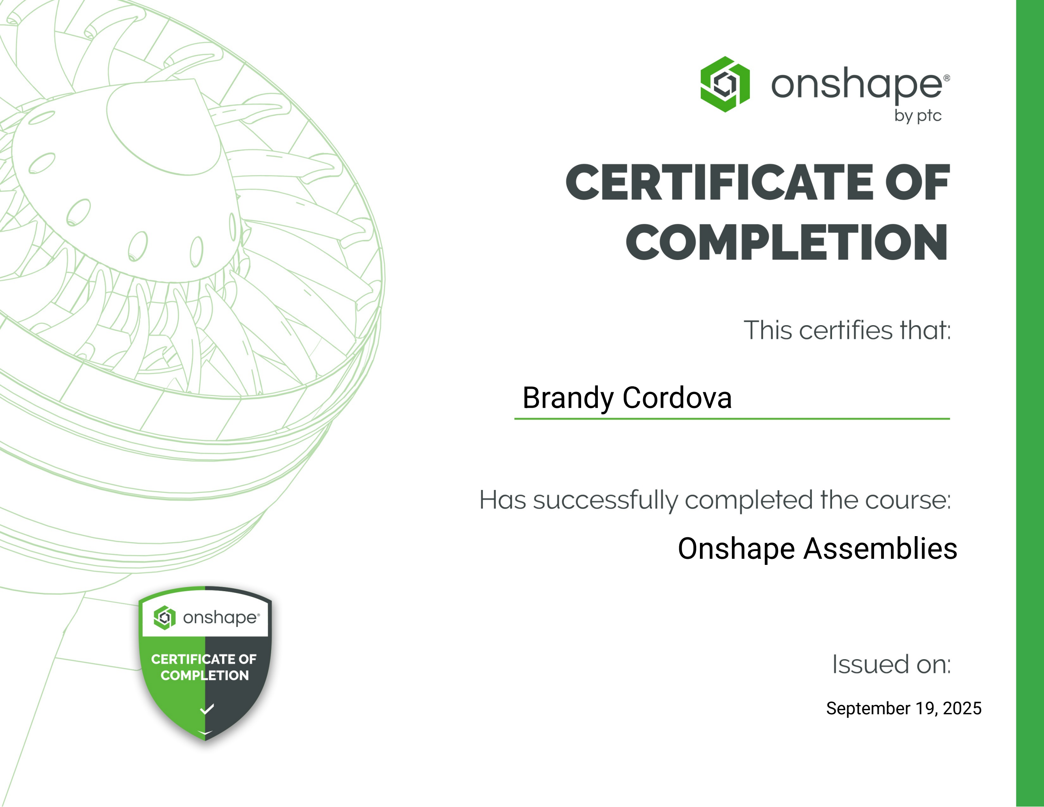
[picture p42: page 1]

Brandy Cordova

September 19, 2025

Onshape Assemblies

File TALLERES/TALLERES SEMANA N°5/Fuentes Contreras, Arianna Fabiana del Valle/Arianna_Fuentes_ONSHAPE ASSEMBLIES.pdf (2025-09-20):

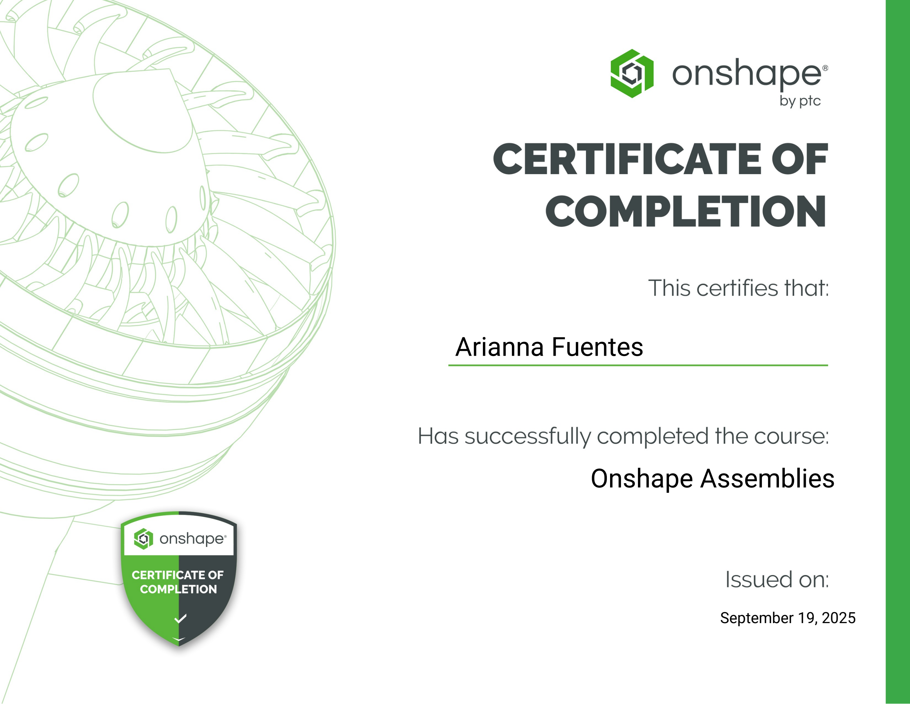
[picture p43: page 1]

Arianna Fuentes

September 19, 2025

Onshape Assemblies

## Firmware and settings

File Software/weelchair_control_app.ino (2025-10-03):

#include <BluetoothSerial.h>
#include <ESP32Servo.h>

// Crear objeto servo
Servo myservo;

// Objeto Bluetooth
BluetoothSerial SerialBT;

// Variables de control
int servoPos = 135;         // Posición inicial (centro)
int targetDirection = -1;   // -1 = STOP, 0 = STRAIGHT, 1 = RIGHT, 2 = LEFT

void setup() {
  myservo.attach(18, 500, 2500);  // Servo en pin 18 (270°)
  
  Serial.begin(9600);
  SerialBT.begin("ESP32_Servo");
  Serial.println("ESP32 listo, conecta desde App Inventor.");

  myservo.write(servoPos);
}

void loop() {
  // Revisar comandos desde la app
  if (SerialBT.available()) {
    int command = SerialBT.read();
    Serial.print("Comando recibido: ");
    Serial.println(command);

    switch (command) {
      case 0:   // STRAIGHT → solo mantener posición actual
        targetDirection = 0;
        break;

      case 45:  // TURN RIGHT
        targetDirection = 1;
        break;

      case 315: // TURN LEFT
        targetDirection = 2;
        break;

      case 200: // STOP
        targetDirection = -1;
        break;

      case 250: // RESET → volver al centro
        servoPos = 135;
        myservo.write(servoPos);
        targetDirection = -1; // se queda quieto después
        break;
    }
  }

  // Movimiento del servo según targetDirection
  if (targetDirection == 1) {        // Girar a la derecha
    if (servoPos < 270) {
      servoPos++;
      myservo.write(servoPos);
      delay(15); // velocidad del giro (ajustable)
    }
  } 
  else if (targetDirection == 2) {   // Girar a la izquierda
    if (servoPos > 0) {
      servoPos--;
      myservo.write(servoPos);
      delay(15);
    }
  }
  // Si targetDirection = 0 (straight) → se queda fijo
  // Si targetDirection = -1 (stop) → se queda fijo
}

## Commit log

2025-08-26 Cara de Nico
2025-08-26 Cara de Mario
2025-10-01 Version 37
    [Lista de características principales.xlsx]
2025-10-03 Version 40
    [Lista de características principales.xlsx, LocatorWedges.stl, Mk6handBase.stl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]
2025-10-08 Rename Imagen de WhatsApp 2025-10-07 a las 22.07.38_8c09a05e.jpg to Caja Negra - Aplicación Móvil para Control de Silla de Ruedas Eléctrica con Eye-Tracking
2025-10-15 Rename ENTREGABLE N°7 (Errores de conversion corregidos).pdf to ENTREGABLE N°7
2025-10-21 Version 50
    [Base de la mano electrónica.stl, Caja maestra.stl, Fundas para el joystick de la silla.stl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]
2025-11-05 Version 55
    [Mano Electrónica STL.stl]
